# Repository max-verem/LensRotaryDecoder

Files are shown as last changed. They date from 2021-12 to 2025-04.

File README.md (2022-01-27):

# Lens Rotary Decoder

This project cover several cases on getting lens rotation info

## EZ-USB with Canon HJ14ex4.3B

This version cover getting virtual output of Canon HJ14ex4.3B lens output, please [follow](EZ-USB.md) detailed description

## MCU version

This version cover getting virtual output of Canon HJ14ex4.3B lens output and stanalone encoders, please [follow](MCU-NET.md) detailed description

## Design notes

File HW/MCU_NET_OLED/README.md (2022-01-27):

# MCU version of rotary decoder

This version cover both cases:
* Canon HJ14ex4.3B lens virtual output encoder
* Standalone rotary encoders

## Schematic
schematic

## PCB
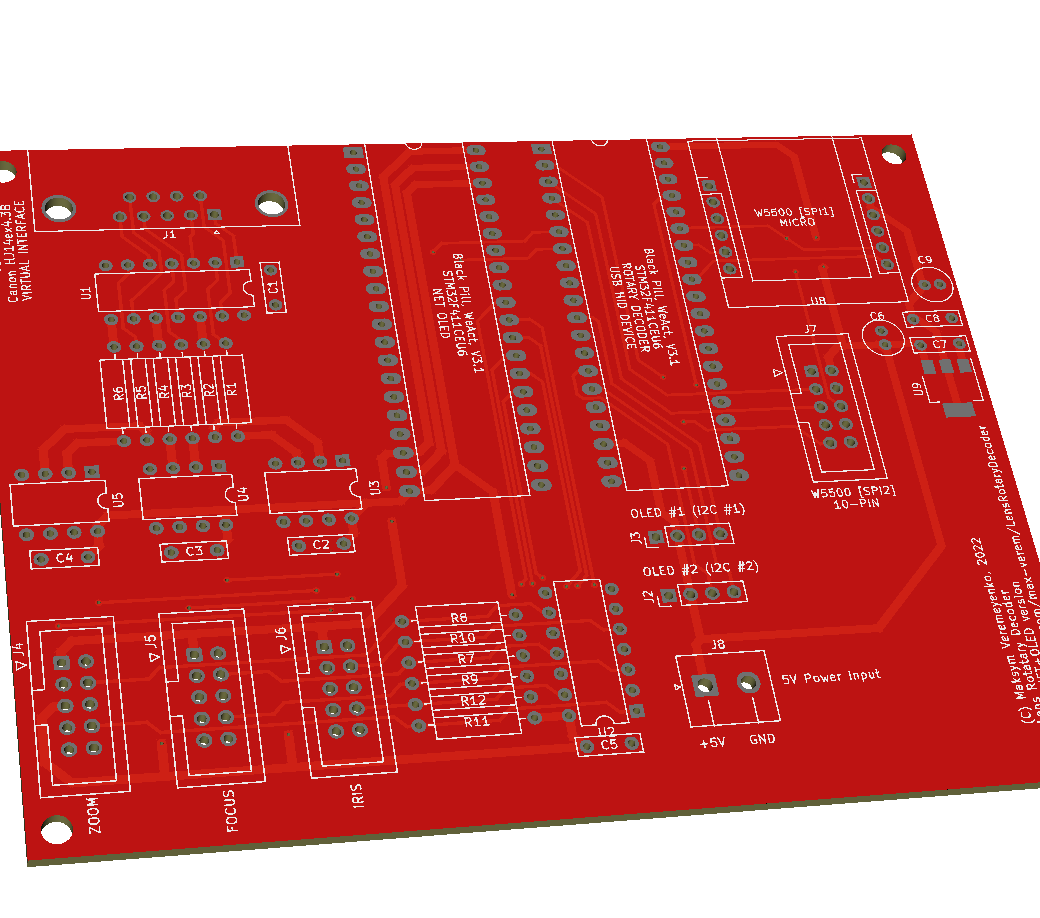
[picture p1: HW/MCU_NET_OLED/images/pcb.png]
pcb


[gerber file](gerber/)

## Firmware

* [rotary decoder firmware source](../../STM32/STM32F411CEU6_RotaryDecoder_3X)
* [NET OLED interface firmware source](../../STM32/STM32F411CEU6_FPGA_UART)

## Hardcoded things

* MAC address of this device is **BA:DE:C0:DE:XX:00** where **XX* is a *unique* hex value for that board
* IP address of FreeD receiver is broadcast (255.255.255.255), destination port is **60000** + **XX**

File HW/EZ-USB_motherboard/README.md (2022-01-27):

# EZ-USB (CY7C68013A EZ-USB FX2LP) based decoder board for Canon HJ14ex4.3B IRSE 

## Schematic
schematic

## PCB
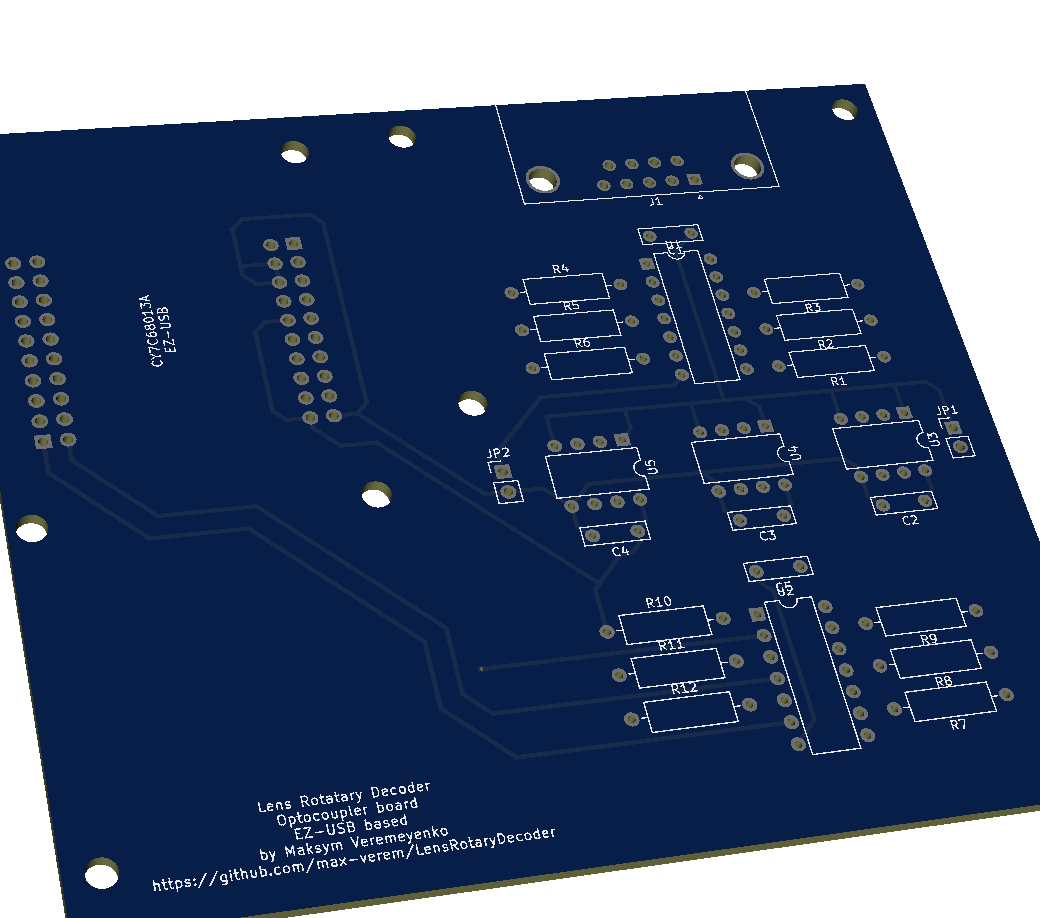
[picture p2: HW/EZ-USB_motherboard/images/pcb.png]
pcb


## GERBER
You can download [gerber archive here](gerber/)

## Final board
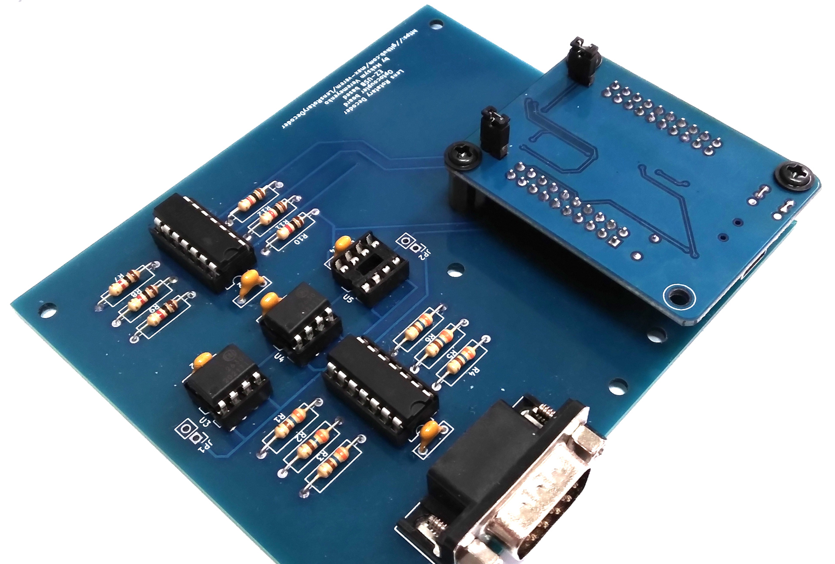
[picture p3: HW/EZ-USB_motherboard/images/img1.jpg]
view 1

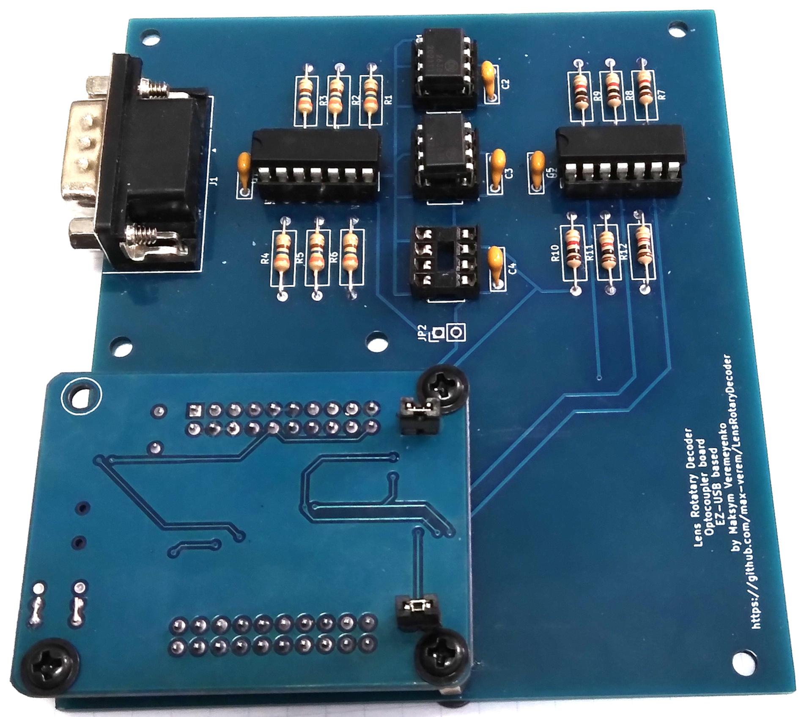
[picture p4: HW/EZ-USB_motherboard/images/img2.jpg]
view 2


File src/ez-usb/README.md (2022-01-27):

# EZ-USB (CY7C68013A EZ-USB FX2LP) based decoder software for Canon HJ14ex4.3B IRSE

## udev (autoloading firmware for EZ-USB)

**/etc/udev/rules.d/90-fx.rules**:
```
SUBSYSTEM=="usb", ACTION=="add", ATTR{idVendor}=="04b4", ATTR{idProduct}=="8613", SYMLINK+="fx2lp-devkit", RUN+="/usr/sbin/fxload -D $tempnode -t fx2lp -I /usr/share/sigrok-firmware/fx2lafw-sigrok-fx2-8ch.fw.hex"
```
make sure **fxload** and **sigrok** packages installed

## diagnostic

after connecting this board to usb port you should notice log messages:
```
[700467.647356] usb 1-1.2: new high-speed USB device number 53 using dwc_otg
[700467.747908] usb 1-1.2: New USB device found, idVendor=04b4, idProduct=8613, bcdDevice=a0.01
[700467.747927] usb 1-1.2: New USB device strings: Mfr=0, Product=0, SerialNumber=0
[700467.748835] usbtest 1-1.2:1.0: FX2 device
[700467.748853] usbtest 1-1.2:1.0: high-speed {control bulk-in bulk-out} tests (+alt)
[700467.845413] usb 1-1.2: USB disconnect, device number 53
[700469.351363] usb 1-1.2: new high-speed USB device number 54 using dwc_otg
[700469.452666] usb 1-1.2: New USB device found, idVendor=1d50, idProduct=608c, bcdDevice= 0.01
[700469.452690] usb 1-1.2: New USB device strings: Mfr=1, Product=2, SerialNumber=3
[700469.452705] usb 1-1.2: Product: fx2lafw
[700469.452720] usb 1-1.2: Manufacturer: sigrok
[700469.452735] usb 1-1.2: SerialNumber: sigrok FX2 8ch
```
and **lsusb** will show:
```
Bus 001 Device 054: ID 1d50:608c OpenMoko, Inc. Fx2lafw
```

## operating
binary start:
```
./ez_usb_rot_dec --freed-target=10.1.5.65:50050 --freed-div=150 --freed-id=8
```
where:
* *--freed-target=10.1.5.65:50050* is a target host:port where FreeD packet will be sent
* *--freed-id=8*  is a camera id in FreeD protocol
* *--freed-div=150* defines a rate for sending UDP packets to FreeD received, this value is a divider of USB transfers counter
* *--log-file-name=/tmp/log* where log will be save
* *--demonize* start in daemon mode

after startup in non-daemon mode it outputs logs and statistic:
```
  [2022-01-27 10:06:27.543] ez_usb_rot_dec-v1.0-86-gd7c67b8, Copyright by Maksym Veremeyenko (c) 2022
  [2022-01-27 10:06:27.544] ez_usb_reader_proc: Searching for 1D50:608C
  [2022-01-27 10:06:27.544] freed_sender_proc: Entering....
! [2022-01-27 10:06:27.548] freed_sender_proc: new target [10.1.5.65:50050]
! [2022-01-27 10:06:27.568] ez_usb_reader_proc: endpoint=130 (0x82)
! [2022-01-27 10:06:27.569] ez_usb_reader_proc: fw_version Major=01, Minor=04, revision 01
! [2022-01-27 10:06:27.586] command_start_acquisition: GPIF delay = 11, clocksource = 48MHz.
  [2022-01-27 10:06:27.586] counter_proc: Entering...
|          0 |          0 |          0| [       27078656  ]
```

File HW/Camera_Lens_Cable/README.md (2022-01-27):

# Hirose 20 Pin Male HR25-9P-20P for Canon HJ14ex4.3B IRSE

## Schematic

Cable

## Assembling

You can use separate connector **Hirose HR25A-9P-20P** connector:
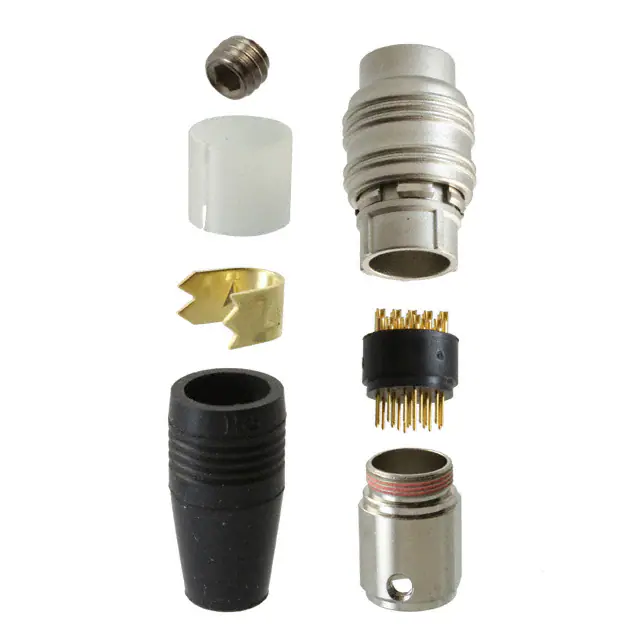
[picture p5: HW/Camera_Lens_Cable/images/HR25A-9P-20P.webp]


and assemble cable:
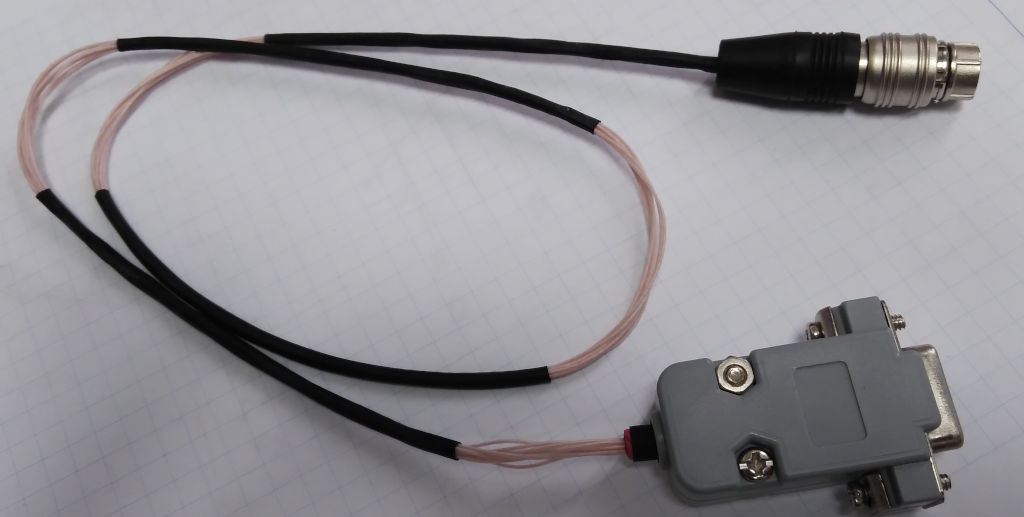
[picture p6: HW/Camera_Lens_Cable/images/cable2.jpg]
Cable


another way is to buy cable with soldered **Alvin’s Cables Hirose 20 Pin Male HR25-9P-20P to Open End Shield Cable for Canon Fujinon ENG Lens 1M** cable:
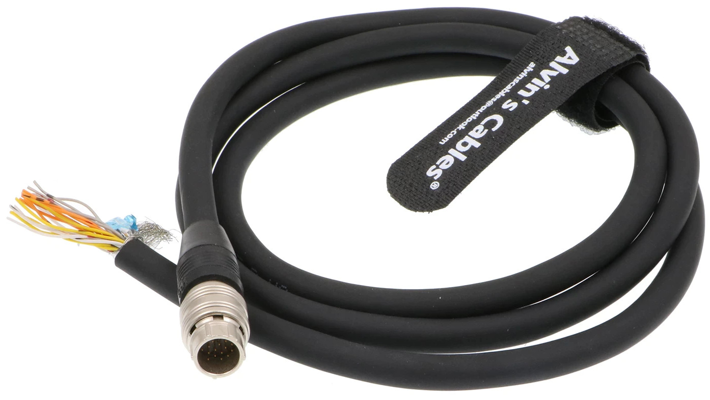
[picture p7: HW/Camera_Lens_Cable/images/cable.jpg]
Cable


that you can buy [here](https://www.aliexpress.com/item/1005001689120693.html) and [here](https://www.amazon.co.uk/Alvins-Cables-Hirose-HR25-9P-20P-Fujinon/dp/B08MC7KPMV)

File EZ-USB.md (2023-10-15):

# EZ-USB (CY7C68013A EZ-USB FX2LP) based decoder for Canon HJ14ex4.3B IRSE virtual output

Lens **Canon HJ14ex4.3B** has output that can provide information from internal rotary encoder.

# Functional schematic
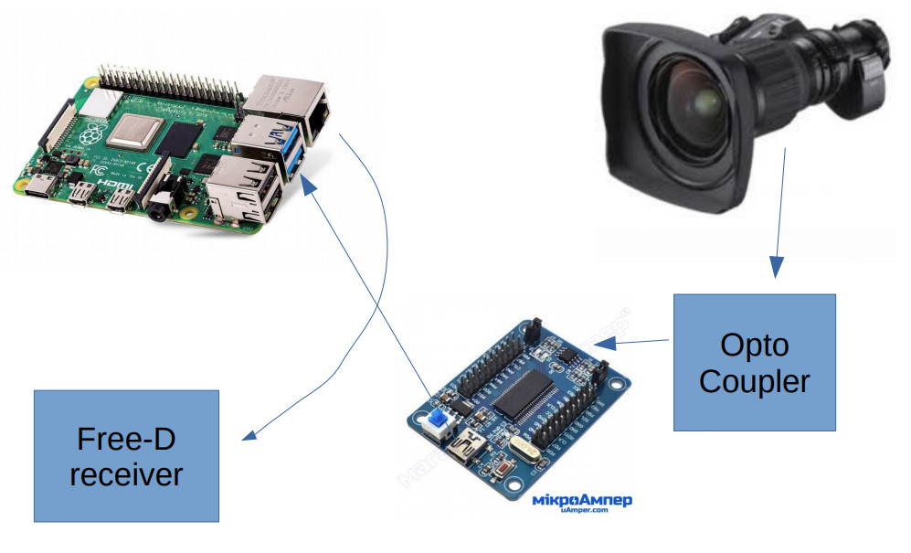
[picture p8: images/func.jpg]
func


# Signal direction
* [Cable](HW/Camera_Lens_Cable/) connected to first lens output provides rotary decoder info of Zoom/Focus/Iris
* This data sent to [opto-isolator board](HW/EZ-USB_motherboard/) that bridged with CY7C68013A based logic analizer board
* Logic analizer connected by USB cable mini-pc
* [Software](src/ez-usb/) that perform decoding of raw data received from lens installed on mini pc. After decoding, it compose Free-D packets sent to reciever (render station or [lens calibrarting server](https://github.com/max-verem/VRPN-LensCalibration))

# Final device
for final device standart case was used:

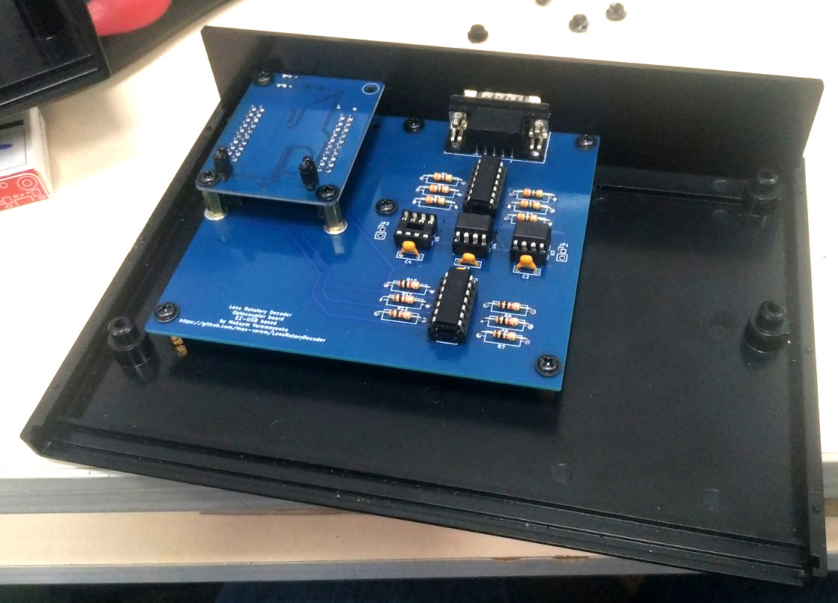
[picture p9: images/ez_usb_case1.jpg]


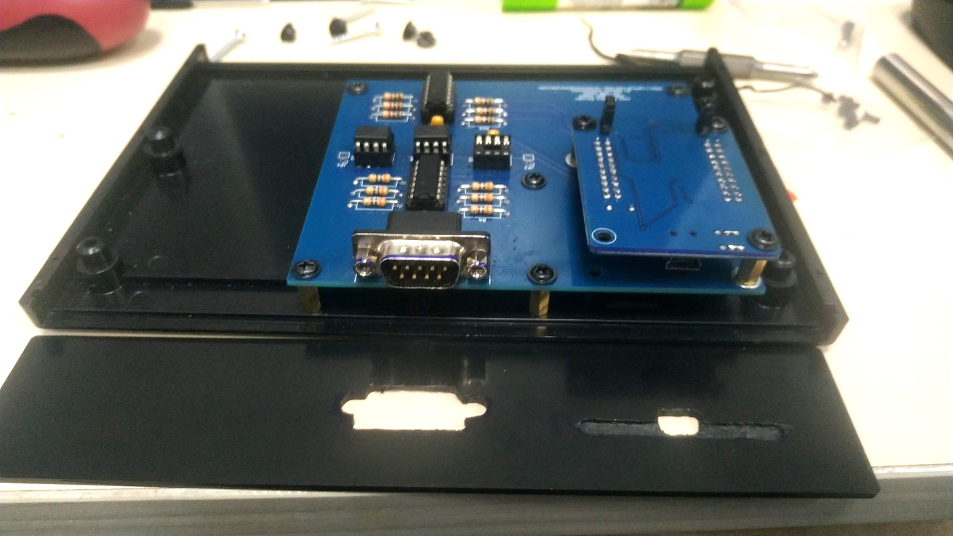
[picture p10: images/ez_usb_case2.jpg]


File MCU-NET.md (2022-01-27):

# MCU version of rotary decoder for Canon HJ14ex4.3B IRSE virtual output or standalone rotary encoders

[Previous](EZ-USB.md) version require a lot of CPU power to decode data, so we developing more simplified version that could also cover standalone encoders support

## Functional diagram
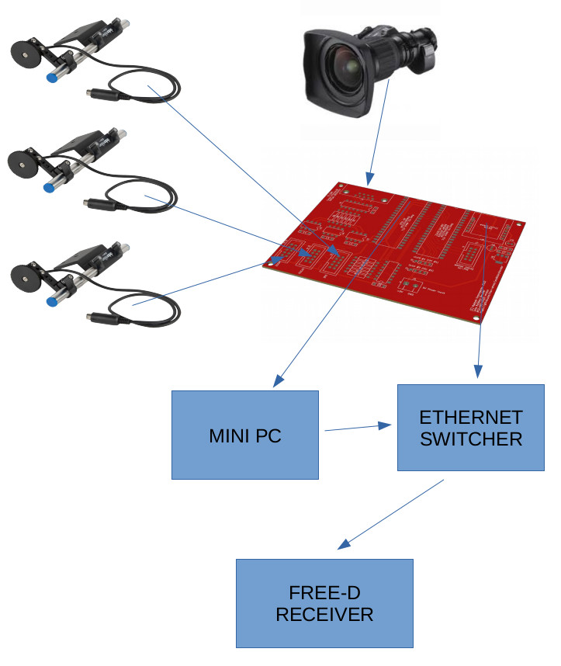
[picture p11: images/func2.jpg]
Functional diagram


## Implementation

[Core board](HW/MCU_NET_OLED/) perform all task for receiving/processing/sending data, it accept [Canon lens cable](HW/Camera_Lens_Cable/) for connecting lens directly.

Standalone encoders:

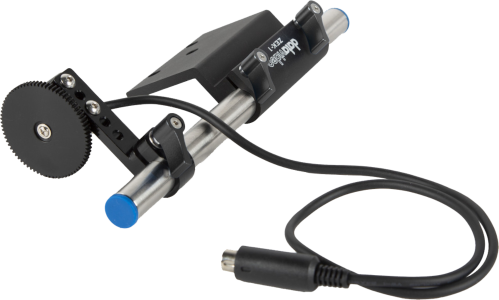
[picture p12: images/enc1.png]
example 1

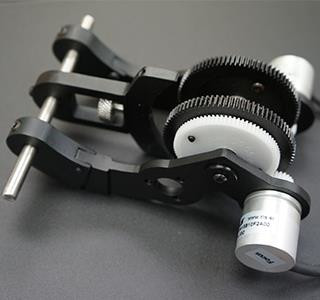
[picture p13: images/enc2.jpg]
example 2
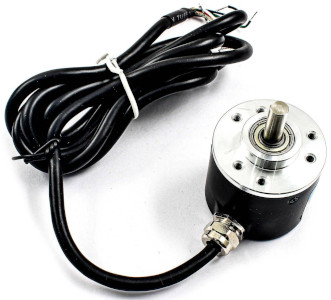
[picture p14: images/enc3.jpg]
example 3
 

could also be connection to that board (for Zoom/Focus/Iris)

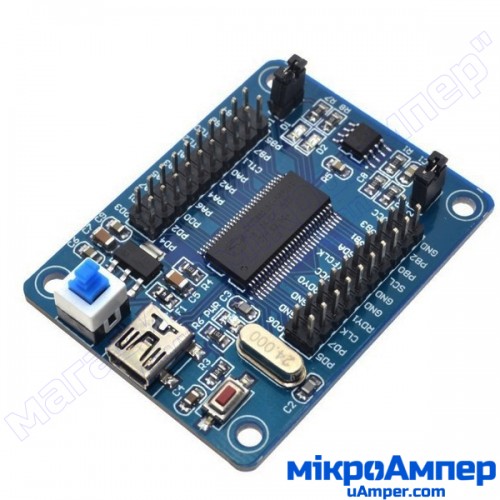
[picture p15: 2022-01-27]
images/ez-usb.jpg

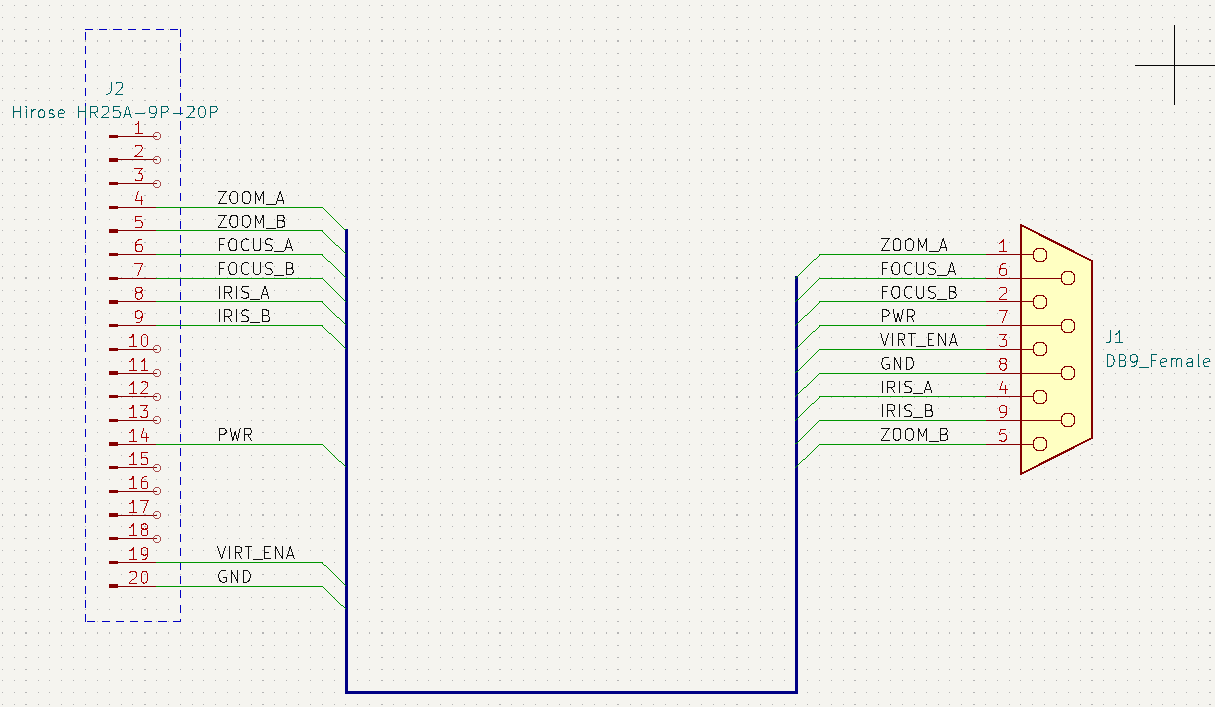
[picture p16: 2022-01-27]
HW/Camera_Lens_Cable/images/pic2.png

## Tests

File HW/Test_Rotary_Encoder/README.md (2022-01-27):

# Test Rotary Encoder

This is a EC11 rotary encoder with debouncing curcuit that is used in this project to debug and simulating purpose.

## Main module
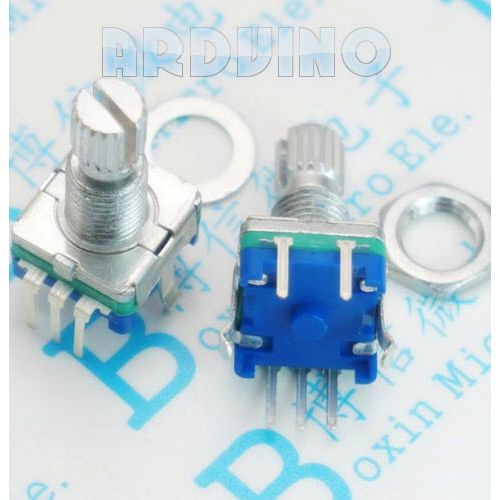
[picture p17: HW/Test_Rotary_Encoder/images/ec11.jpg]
EC11


## Schematic
Schematic

## PCB
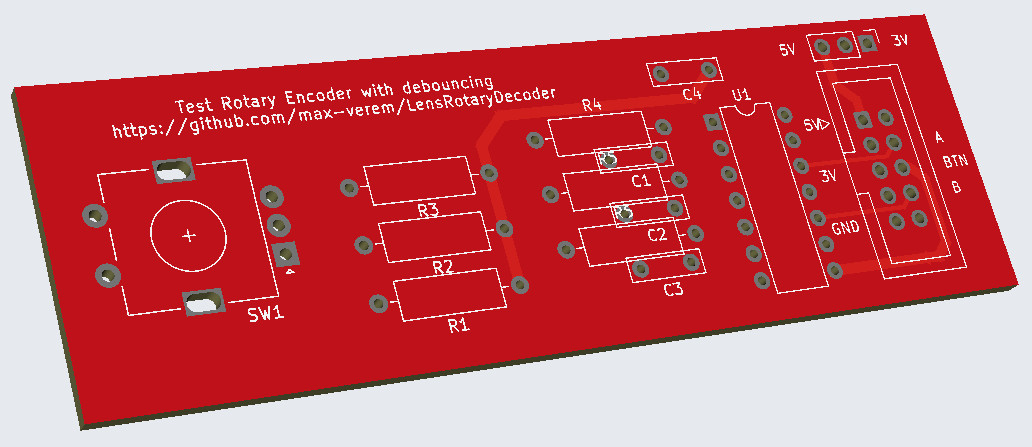
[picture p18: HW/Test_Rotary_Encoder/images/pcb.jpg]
PCB


gerber [file](gerber/)

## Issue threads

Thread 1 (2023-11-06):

encoder in Canon Lens

tappete, 2023-11-06:
Hi, I'm very interested of  this project and I would like to be able to send the encoder data to Arduino but I can't decode the output pulses from a Canon lens (I work in television and I have a lens like yours with Virtual Output).
I can read the data of the classic rotary encoders without any kind of problem but nothing to do for those integrated in the Canon lens, even after having created your circuit and taken the output pulses.
Are the Canon optics encoders different, what is the problem?

Many thanks and I hope you can help me!

Best regards,
Davide

max-verem, 2023-11-06:
I am not sure if Arduino has enough cpu power to decode sequence from lens. have a look on diagram:

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

A/B pulses distance is about 1us.

tappete, 2023-11-06:
ok, so the output is a quadrature but very fast...

Thank you

Closed 2023-11-06.

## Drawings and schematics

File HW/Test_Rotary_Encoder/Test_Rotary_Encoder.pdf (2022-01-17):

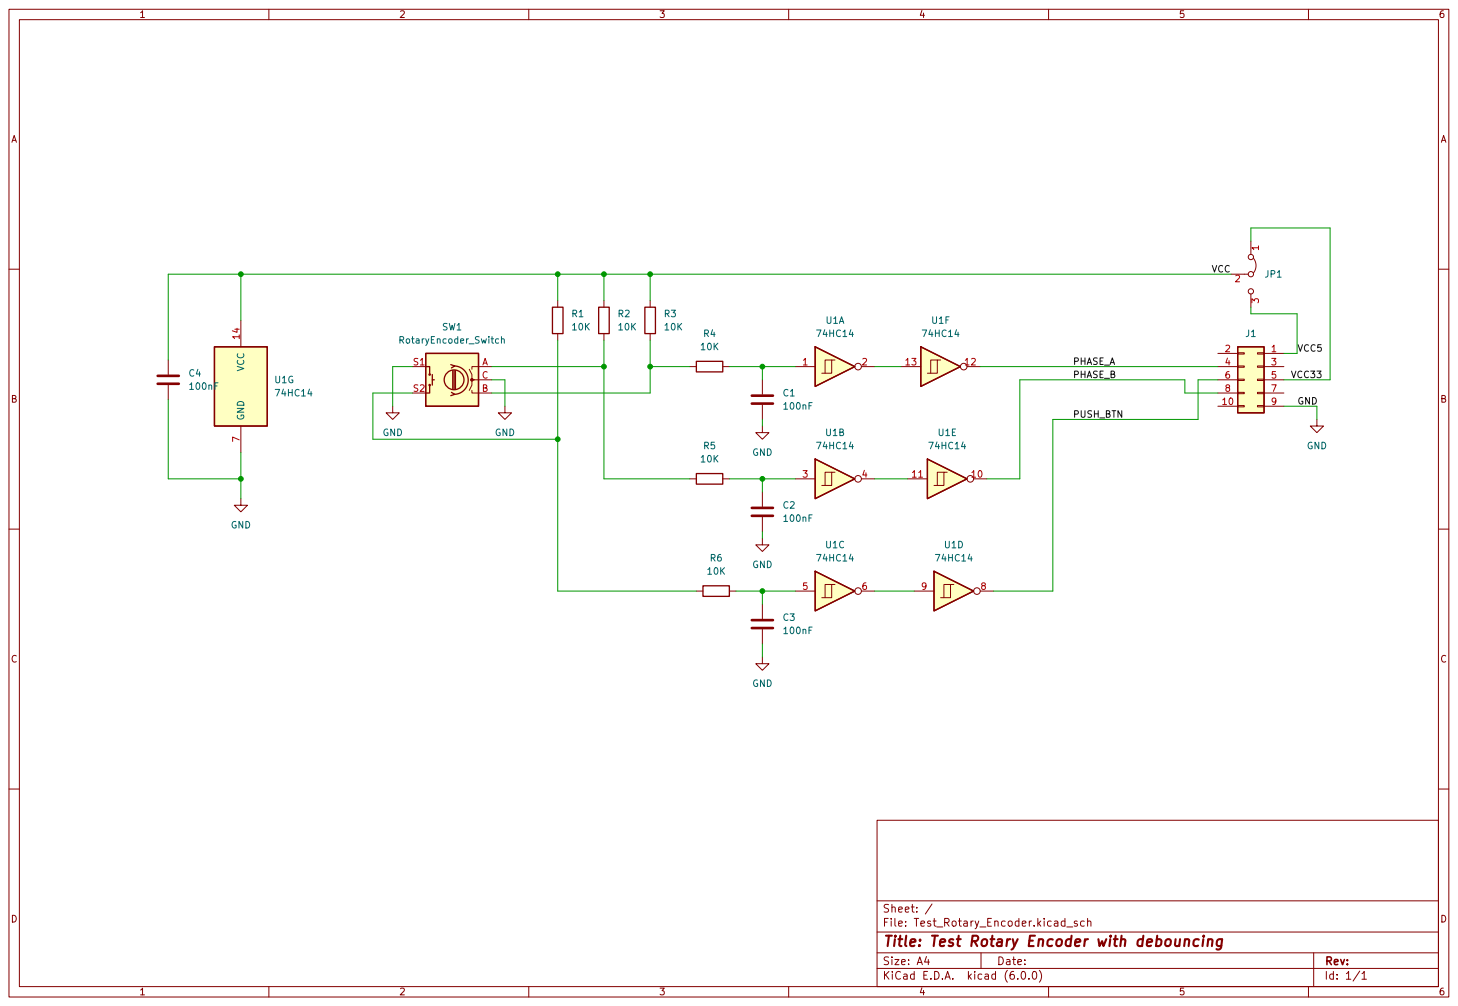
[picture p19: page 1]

File: Test_Rotary_Encoder.kicad_sch Sheet: / VCC 14 GND

Id: 1/1 Title: Test Rotary Encoder with debouncing

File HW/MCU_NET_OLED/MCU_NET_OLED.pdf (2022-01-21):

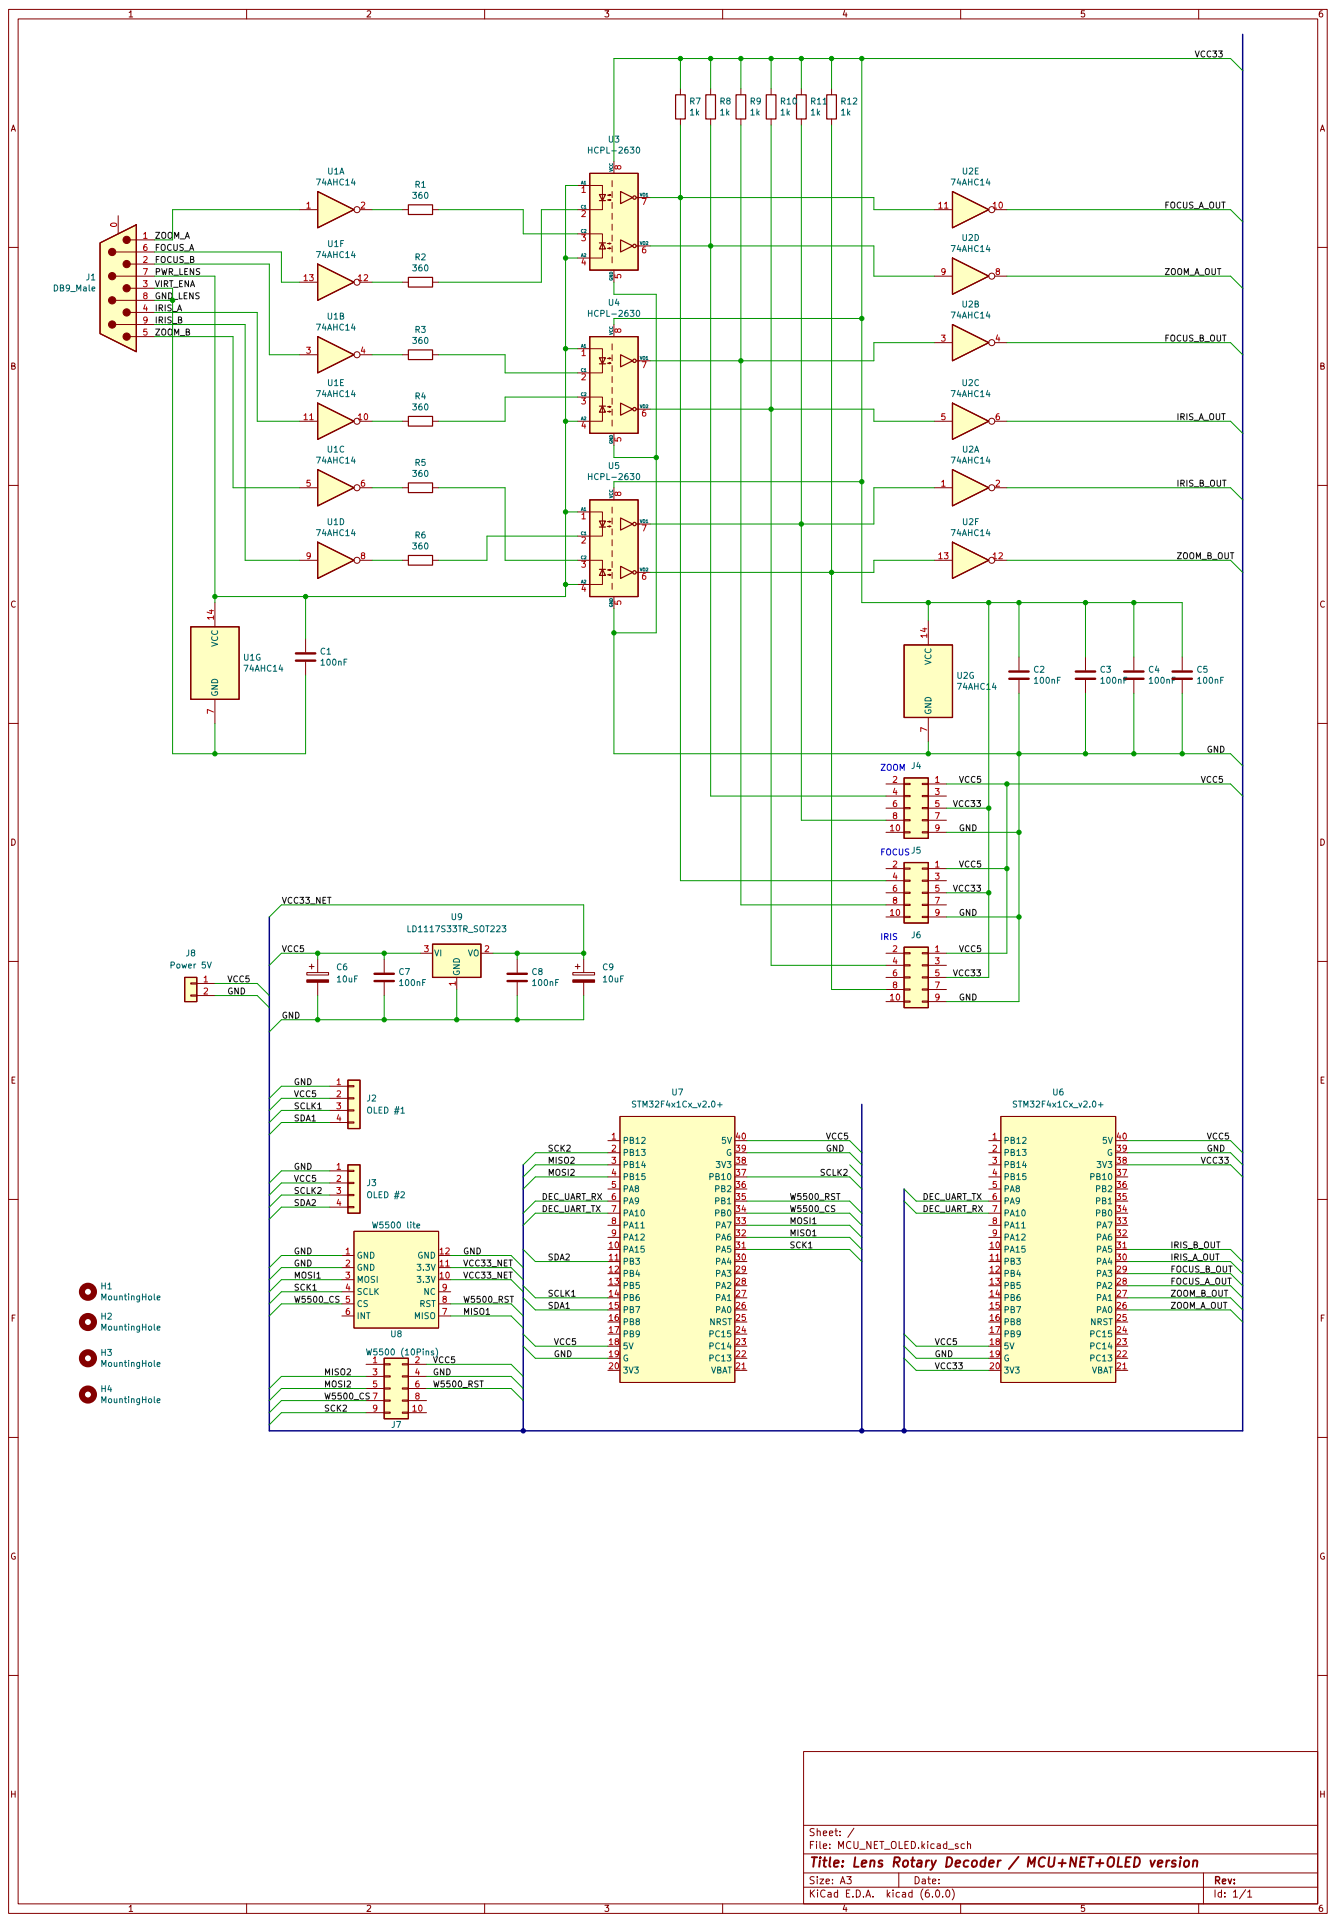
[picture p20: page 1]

File: MCU_NET_OLED.kicad_sch Sheet: /
Id: 1/1 Title: Lens Rotary Decoder / MCU+NET+OLED version

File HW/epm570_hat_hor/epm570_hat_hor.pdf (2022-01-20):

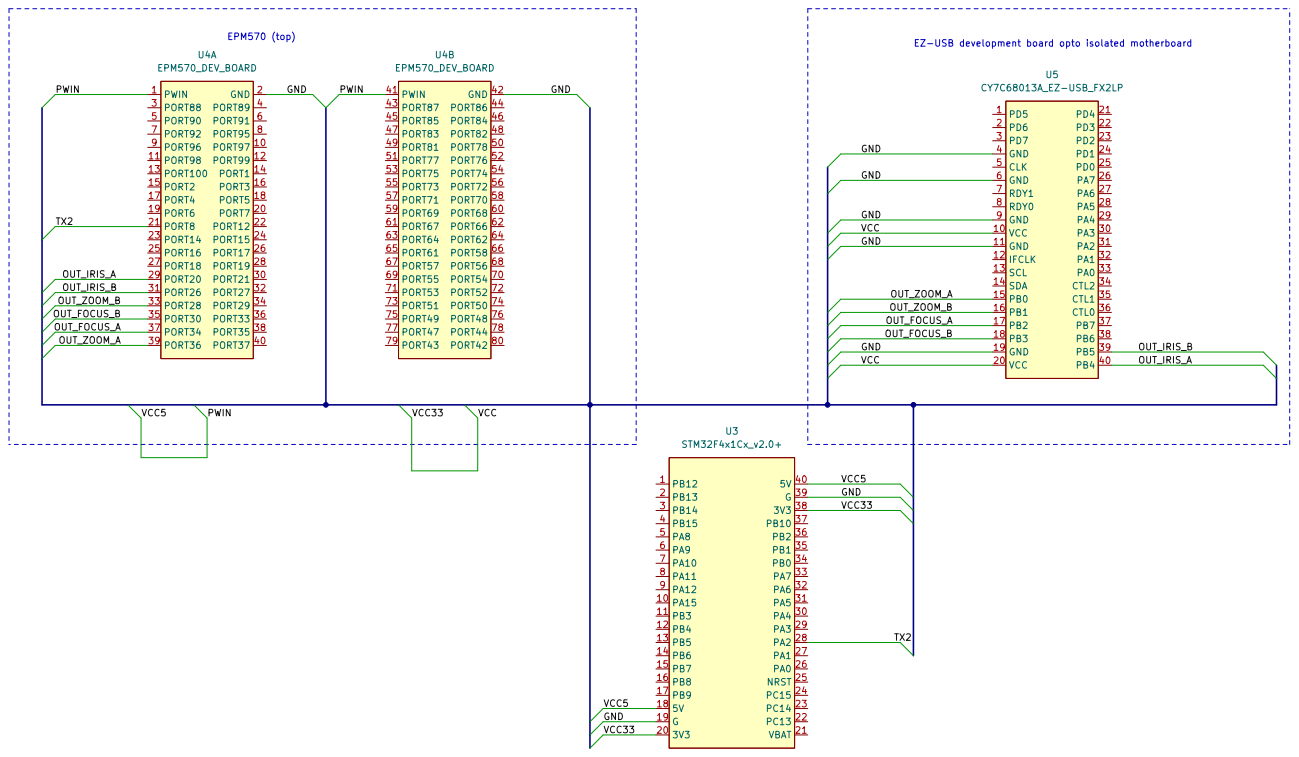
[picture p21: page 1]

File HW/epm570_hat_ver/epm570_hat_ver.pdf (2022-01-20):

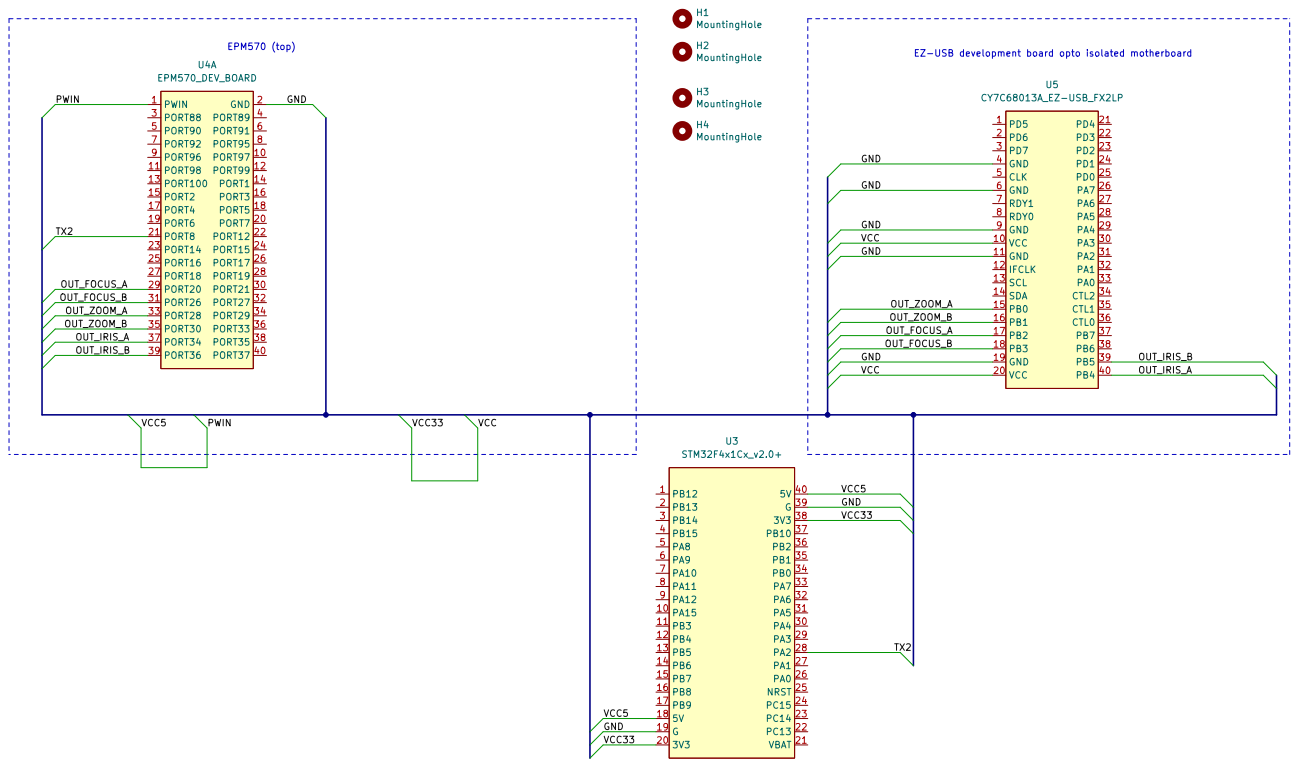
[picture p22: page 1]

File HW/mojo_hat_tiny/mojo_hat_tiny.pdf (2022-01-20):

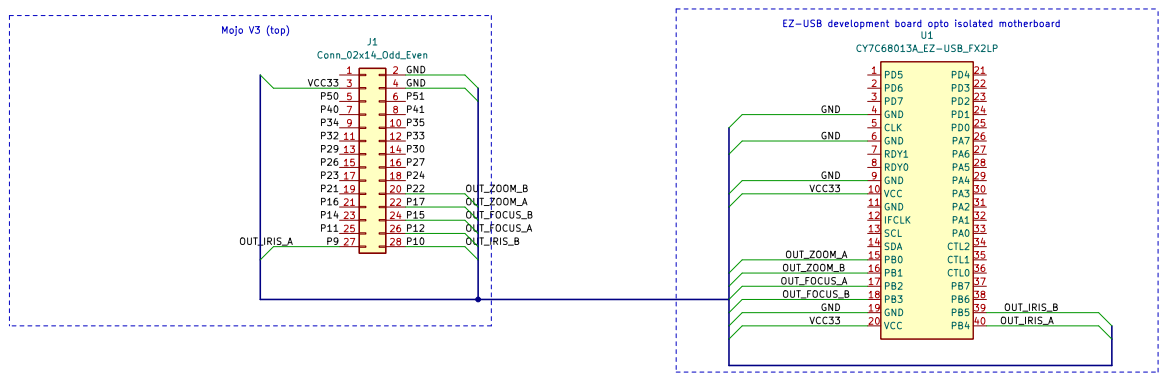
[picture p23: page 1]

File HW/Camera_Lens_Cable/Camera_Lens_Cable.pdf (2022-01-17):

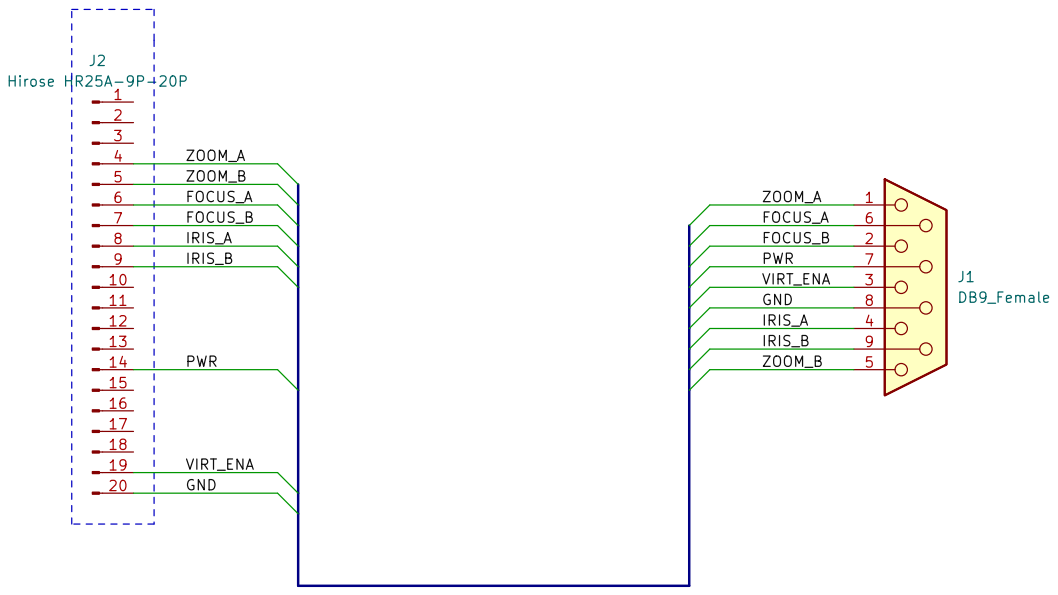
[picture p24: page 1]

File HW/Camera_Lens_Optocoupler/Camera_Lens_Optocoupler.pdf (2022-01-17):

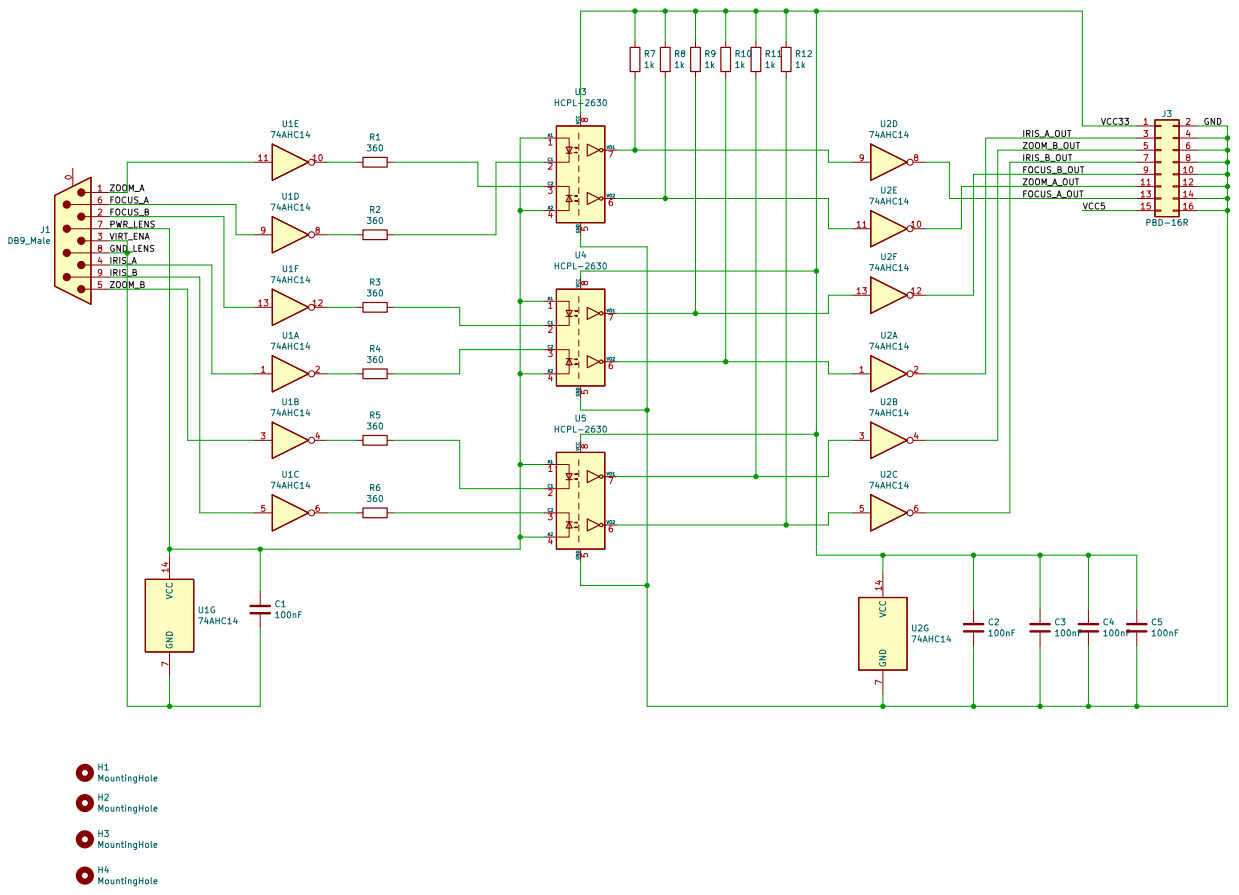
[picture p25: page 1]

11 | | 12
13 | | 14

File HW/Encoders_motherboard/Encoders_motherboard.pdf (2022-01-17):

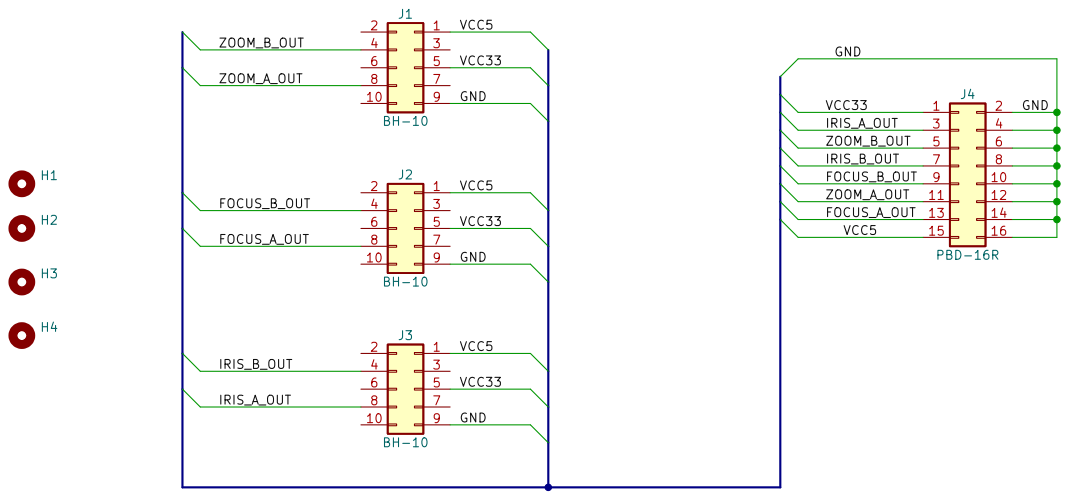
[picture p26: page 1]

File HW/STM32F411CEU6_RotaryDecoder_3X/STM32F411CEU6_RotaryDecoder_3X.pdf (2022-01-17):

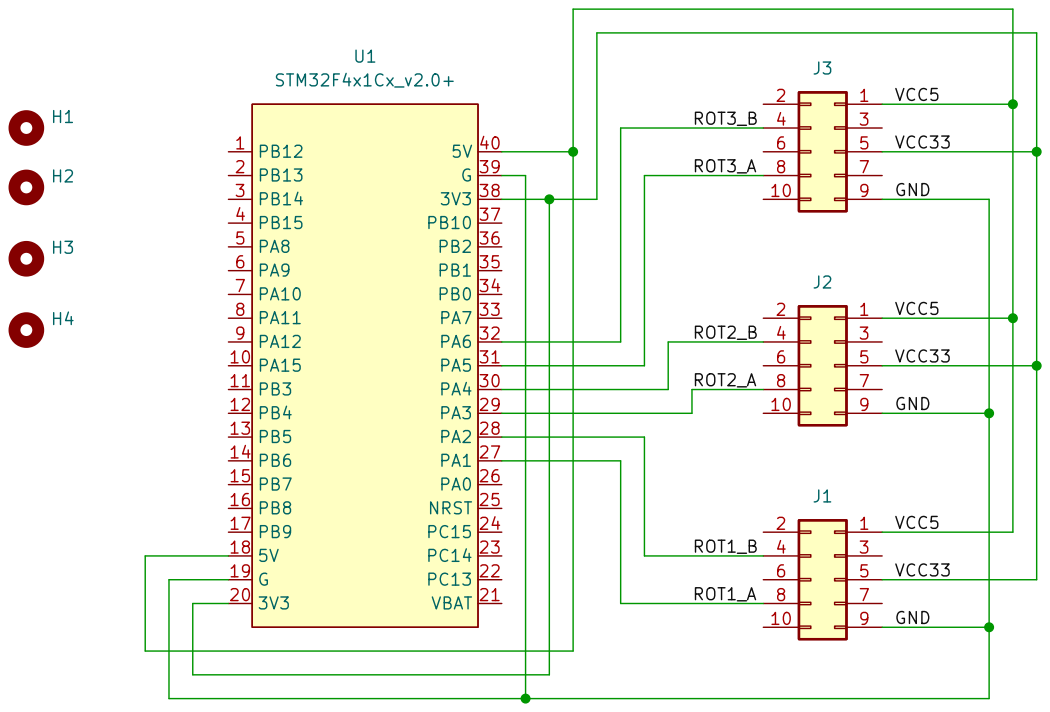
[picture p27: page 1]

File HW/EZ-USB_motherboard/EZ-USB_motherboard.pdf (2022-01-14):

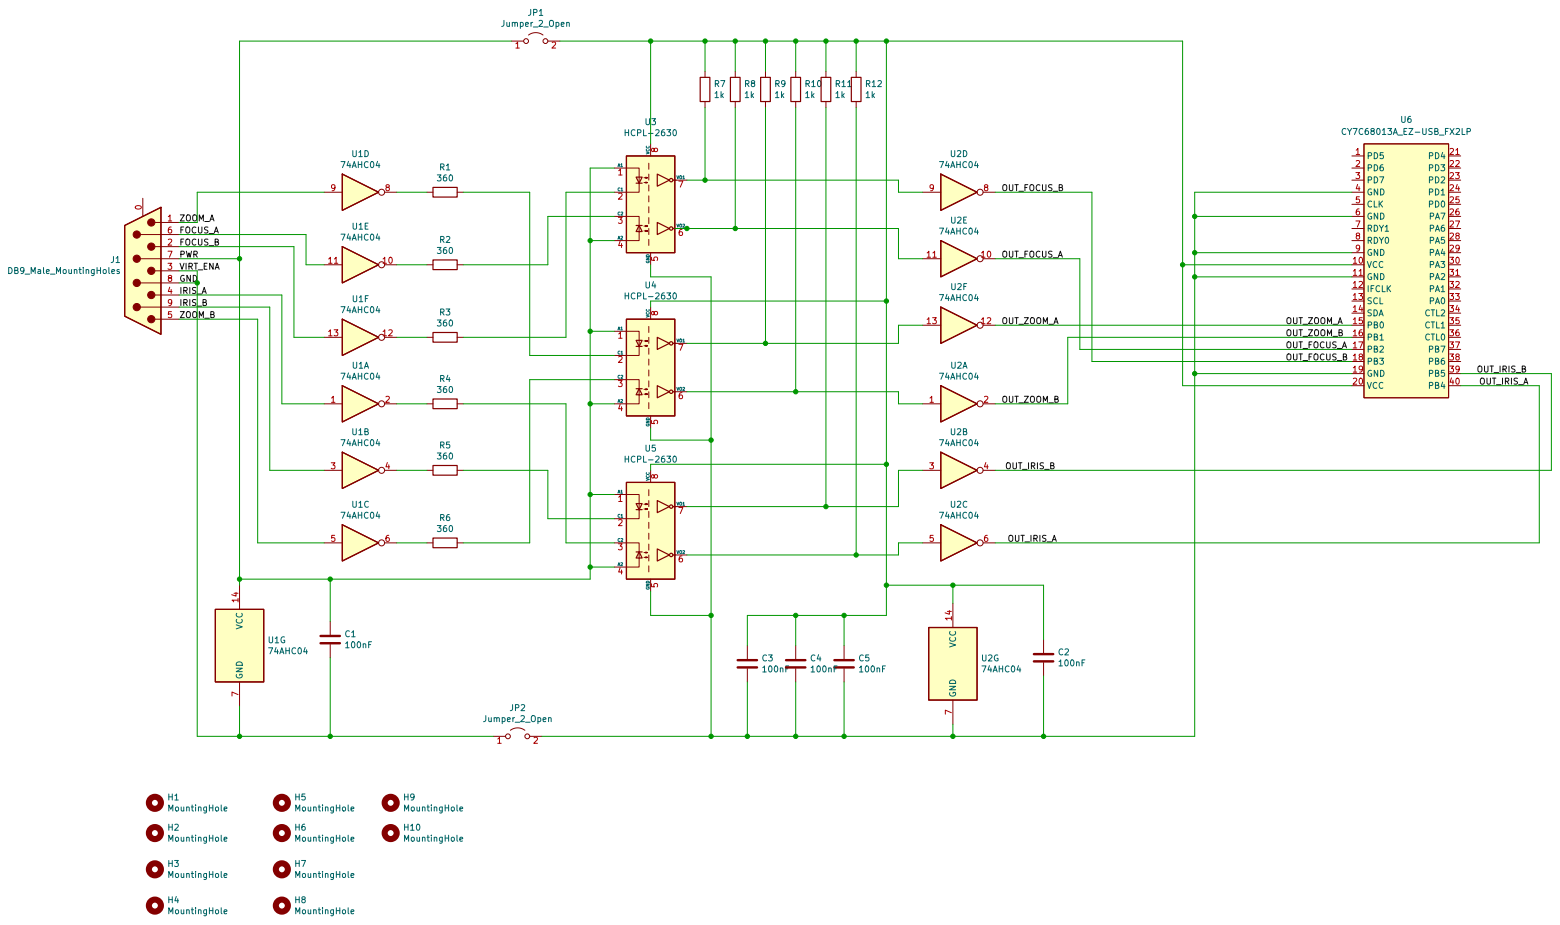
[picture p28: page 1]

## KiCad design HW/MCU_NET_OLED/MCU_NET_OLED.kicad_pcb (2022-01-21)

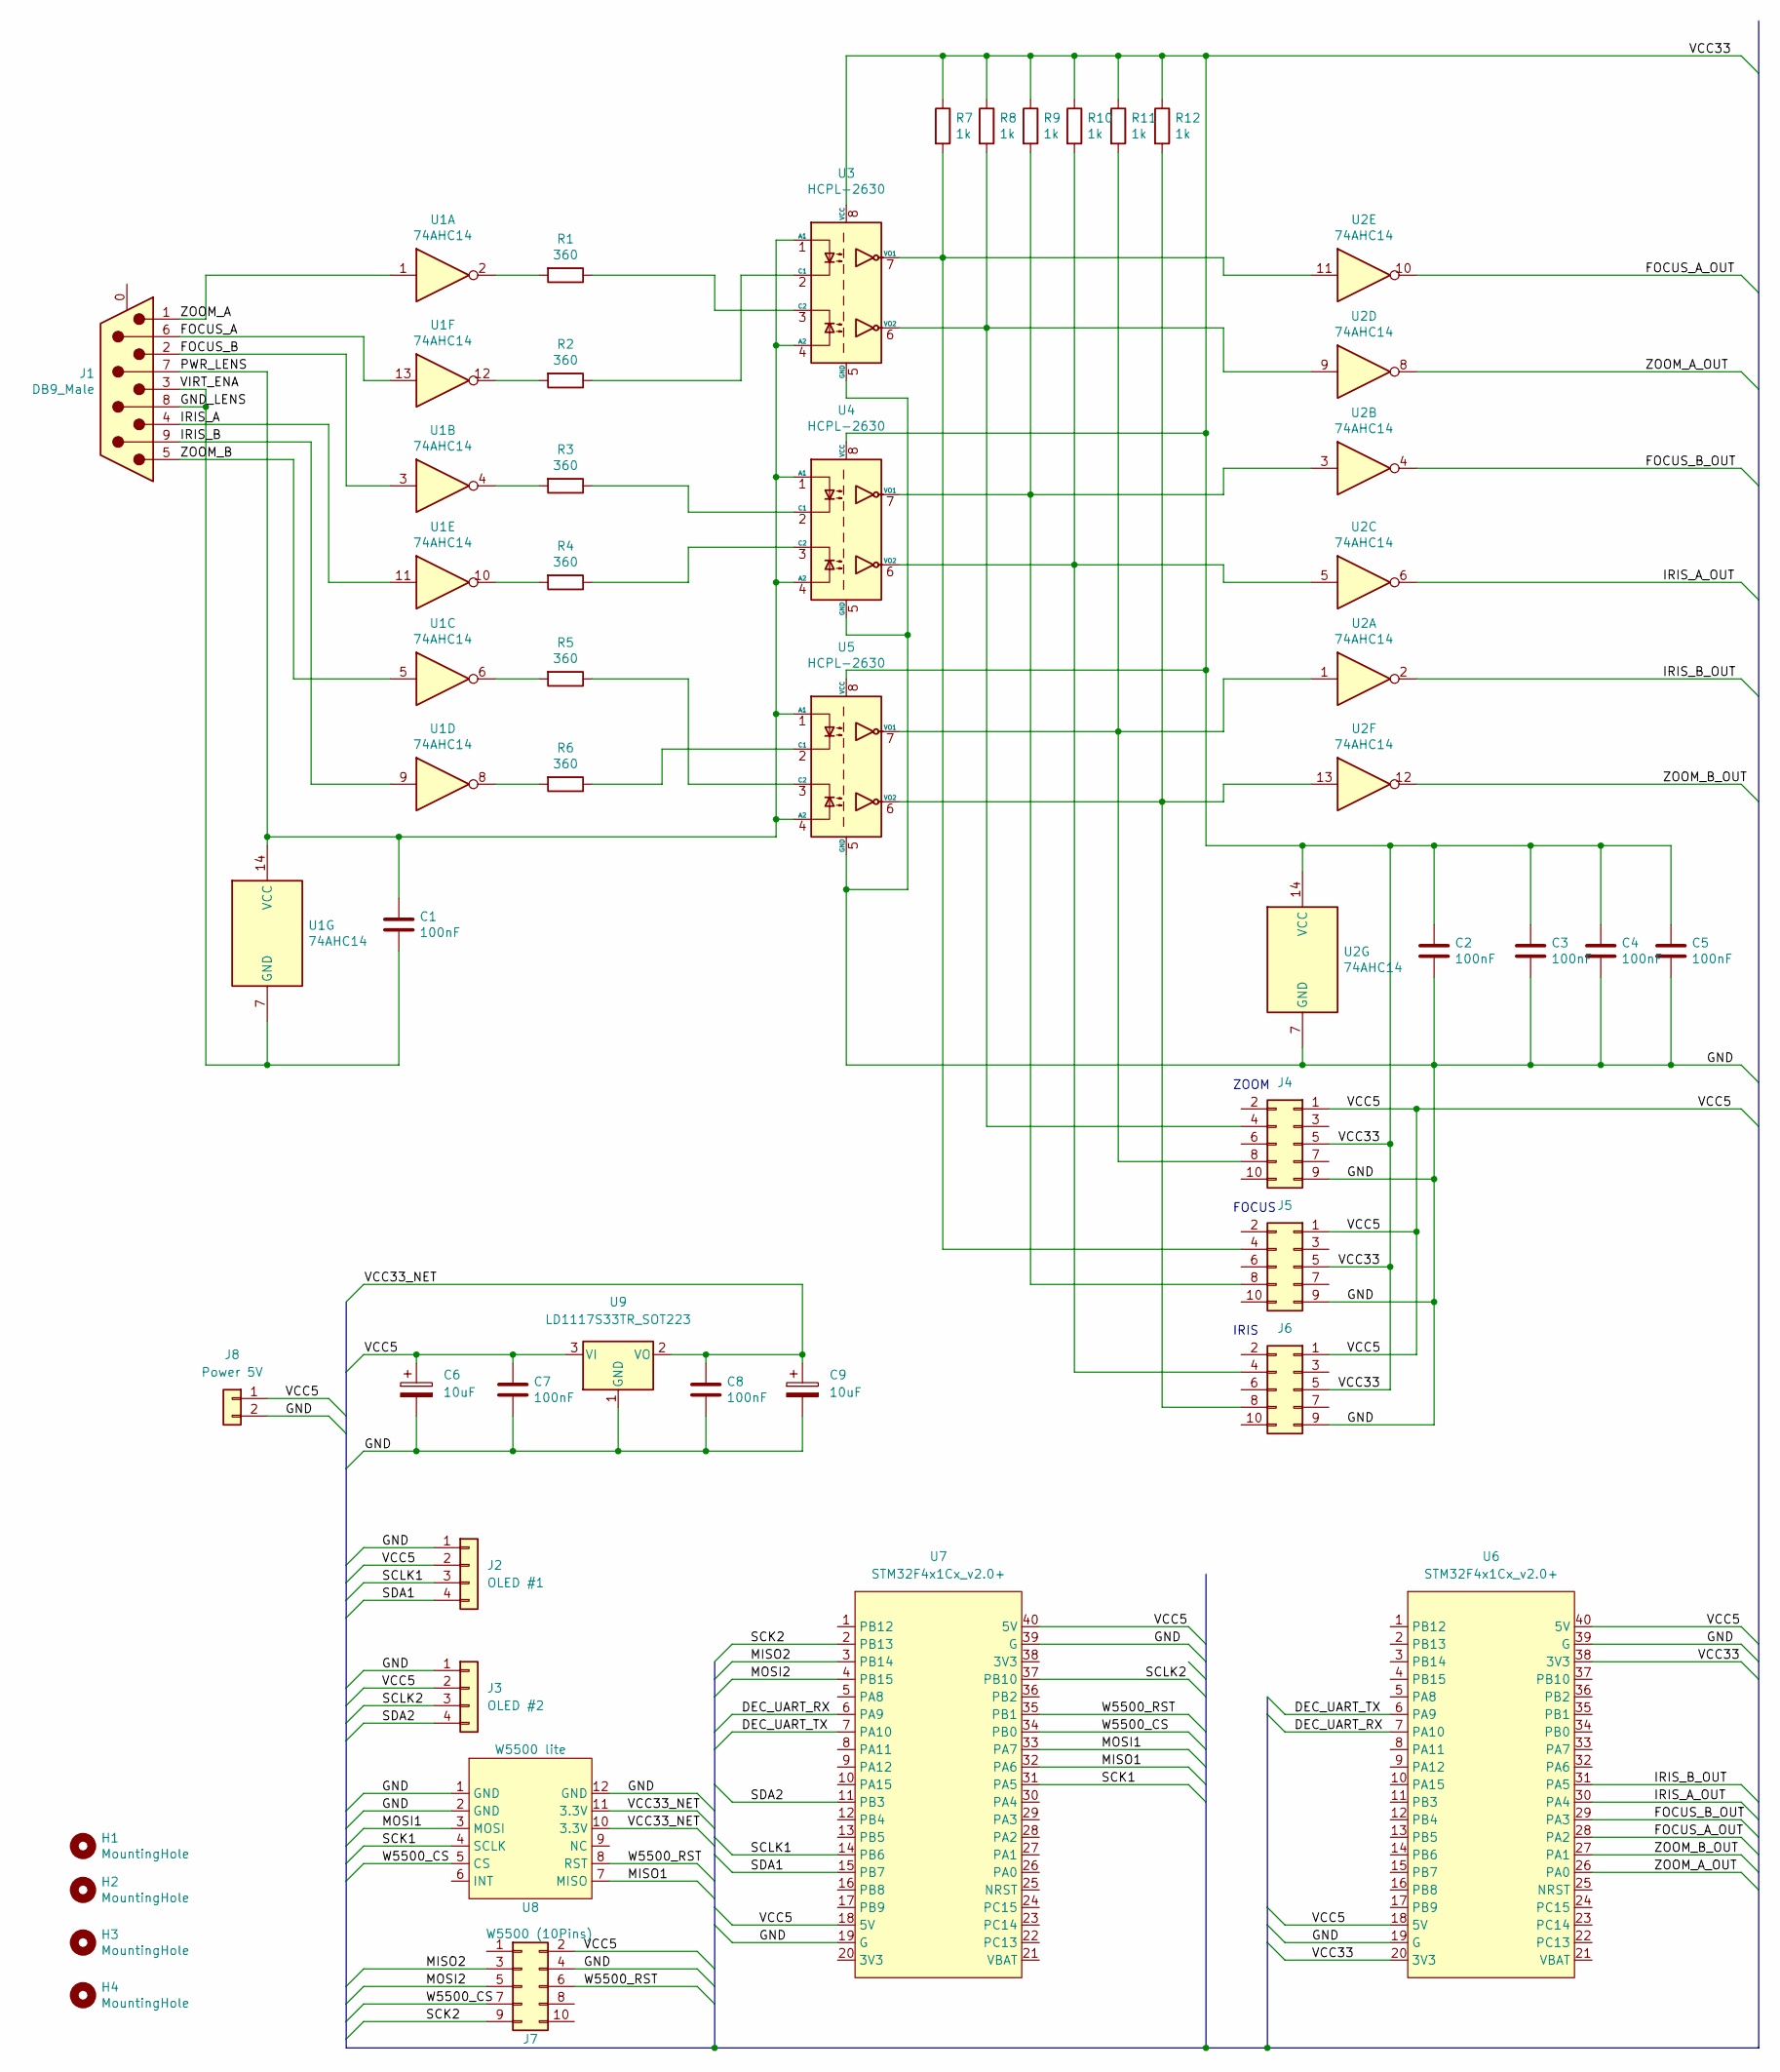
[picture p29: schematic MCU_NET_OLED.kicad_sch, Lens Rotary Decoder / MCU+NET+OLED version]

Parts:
C1, C2, C3, C4, C5, C7, C8: 100nF; C_Rect_L7.0mm_W2.0mm_P5.00mm
C6, C9: 10uF; C_Radial_D5.0mm_H11.0mm_P2.00mm
H1, H2, H3, H4: MountingHole; MountingHole_3.2mm_M3
J1: DB9_Male; DSUB-9_Male_Horizontal_P2.77x2.84mm_EdgePinOffset7.70mm_Hou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
J2: OLED #1; PinHeader_1x04_P2.54mm_Vertical
J3: OLED #2; PinHeader_1x04_P2.54mm_Vertical
J4, J5, J6: Conn_02x05_Odd_Even; IDC-Header_2x05_P2.54mm_Vertical
J7: W5500 (10Pins); IDC-Header_2x05_P2.54mm_Vertical
J8: Power 5V; JST_NV_B02P-NV_1x02_P5.00mm_Vertical
R1, R2, R3, R4, R5, R6: 360; R_Axial_DIN0309_L9.0mm_D3.2mm_P12.70mm_Horizontal
R7, R8, R9, R10, R11, R12: 1k; R_Axial_DIN0309_L9.0mm_D3.2mm_P12.70mm_Horizontal
U1, U2: 74AHC14; DIP-14_W7.62mm
U3, U4, U5: HCPL-2630; DIP-8_W7.62mm
U6, U7: STM32F4x1Cx_v2.0+; DIP-40_W15.24mm_LongPads
U8: W5500 lite; W5500
U9: LD1117S33TR_SOT223; SOT-223-3_TabPin2

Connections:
/DEC_UART_RX: U6.7 (PA10), U7.6 (PA9)
/DEC_UART_TX: U6.6 (PA9), U7.7 (PA10)
/FOCUS_A: J1.6, U1.13
/FOCUS_A_OUT: U2.10, U6.28 (PA2)
/FOCUS_B: J1.2, U1.3
/FOCUS_B_OUT: U2.4, U6.29 (PA3)
/GND: C2.2, C3.2, C4.2, C5.2, C6.2, C7.2, C8.2, C9.2, J2.1, J3.1, J4.9, J5.9, J6.9, J7.4, J8.2, U2.7 (GND), U3.5 (GND), U4.5 (GND), U5.5 (GND), U6.19 (G), U6.39 (G), U7.19 (G), U7.39 (G), U8.1 (GND), U8.2 (GND), U8.12 (GND), U9.1 (GND)
/GND_LENS: C1.2, J1.3, J1.8, U1.7 (GND)
/IRIS_A: J1.4, U1.11
/IRIS_A_OUT: U2.6, U6.30 (PA4)
/IRIS_B: J1.9, U1.9
/IRIS_B_OUT: U2.2, U6.31 (PA5)
/MISO1: U7.32 (PA6), U8.7 (MISO)
/MISO2: J7.3, U7.3 (PB14)
/MOSI1: U7.33 (PA7), U8.3 (MOSI)
/MOSI2: J7.5, U7.4 (PB15)
/PWR_LENS: C1.1, J1.7, U1.14 (VCC), U3.1 (A1), U3.4 (A2), U4.1 (A1), U4.4 (A2), U5.1 (A1), U5.4 (A2)
/SCK1: U7.31 (PA5), U8.4 (SCLK)
/SCK2: J7.9, U7.2 (PB13)
/SCLK1: J2.3, U7.14 (PB6)
/SCLK2: J3.3, U7.37 (PB10)
/SDA1: J2.4, U7.15 (PB7)
/SDA2: J3.4, U7.11 (PB3)
/VCC5: C6.1, C7.1, J2.2, J3.2, J4.1, J5.1, J6.1, J7.2, J8.1, U6.18 (5V), U6.40 (5V), U7.18 (5V), U7.40 (5V), U9.3 (VI)
/VCC33: C2.1, C3.1, C4.1, C5.1, J4.5, J5.5, J6.5, R7.1, R8.1, R9.1, R10.1, R11.1, R12.1, U2.14 (VCC), U3.8 (VCC), U4.8 (VCC), U5.8 (VCC), U6.20 (3V3), U6.38 (3V3)
/VCC33_NET: C8.1, C9.1, U8.10 (3.3V), U8.11 (3.3V), U9.2 (VO)
/W5500_CS: J7.7, U7.34 (PB0), U8.5 (CS)
/W5500_RST: J7.6, U7.35 (PB1), U8.8 (RST)
/ZOOM_A: J1.1, U1.1
/ZOOM_A_OUT: U2.8, U6.26 (PA0)
/ZOOM_B: J1.5, U1.5
/ZOOM_B_OUT: U2.12, U6.27 (PA1)
unnamed: R1.1, U3.3 (C2)
unnamed: R1.2, U1.2
unnamed: R2.1, U3.2 (C1)
unnamed: R2.2, U1.12
unnamed: R3.1, U4.2 (C1)
unnamed: R3.2, U1.4
unnamed: R4.1, U4.3 (C2)
unnamed: R4.2, U1.10
unnamed: R5.1, U5.3 (C2)
unnamed: R5.2, U1.6
unnamed: R6.2, U1.8
unnamed: J5.4, R7.2, U2.11, U3.7 (VO1)
unnamed: J4.4, R8.2, U2.9, U3.6 (VO2)
unnamed: J5.8, R9.2, U2.3, U4.7 (VO1)
unnamed: J6.4, R10.2, U2.5, U4.6 (VO2)
unnamed: J4.8, R11.2, U2.1, U5.7 (VO1)
unnamed: J6.8, R12.2, U2.13, U5.6 (VO2)
unnamed: R6.1, U5.2 (C1)

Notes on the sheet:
IRIS
FOCUS
ZOOM

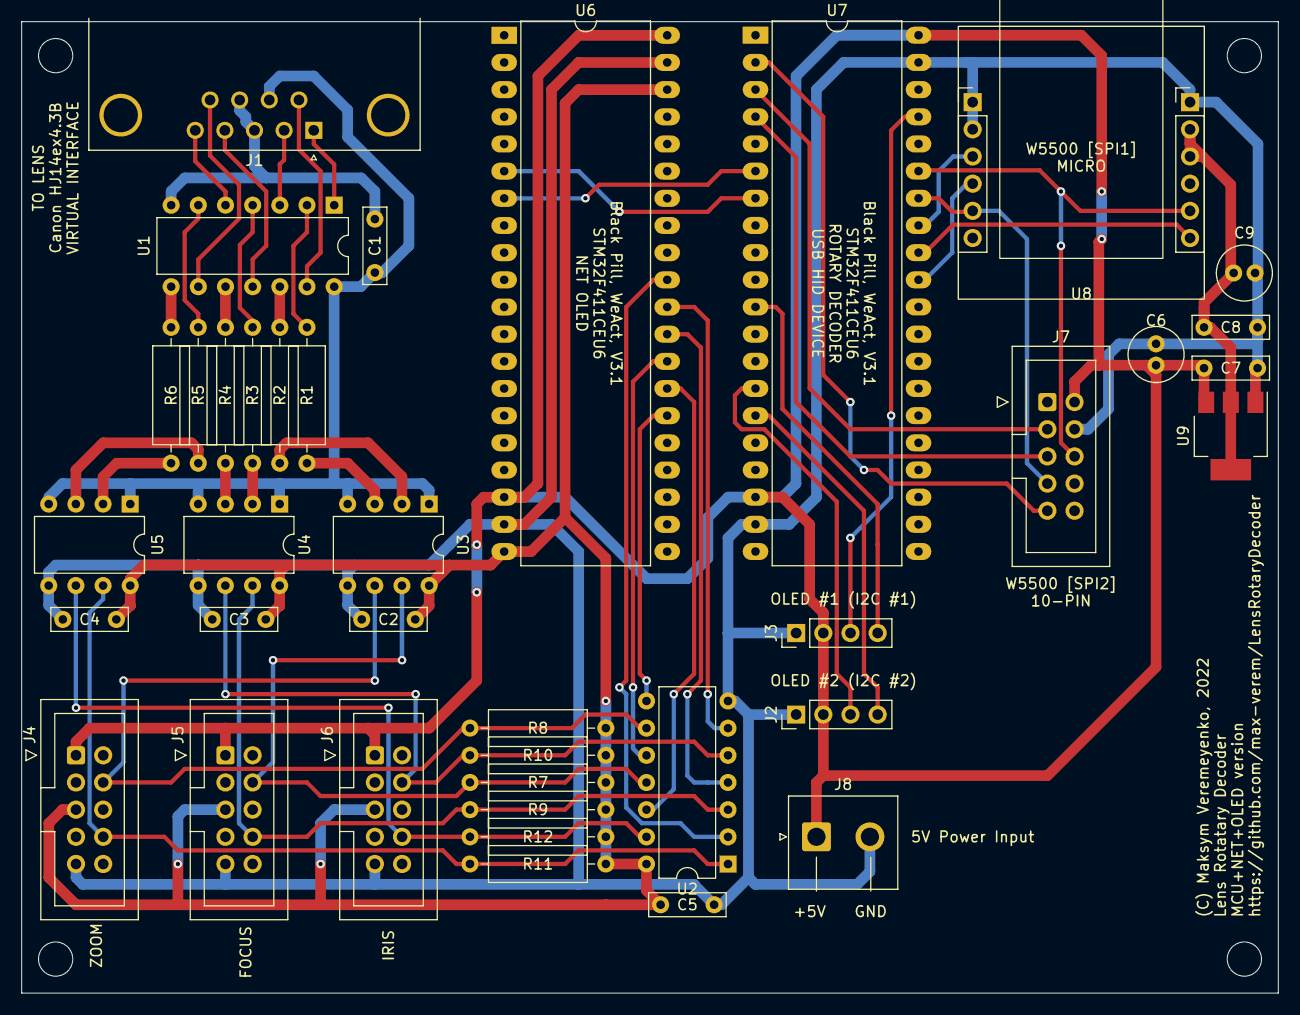
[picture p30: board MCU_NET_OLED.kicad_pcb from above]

Board: 2 copper layers, 117.5 x 90.8 mm, 42 parts (0 on the bottom side), 50 nets.

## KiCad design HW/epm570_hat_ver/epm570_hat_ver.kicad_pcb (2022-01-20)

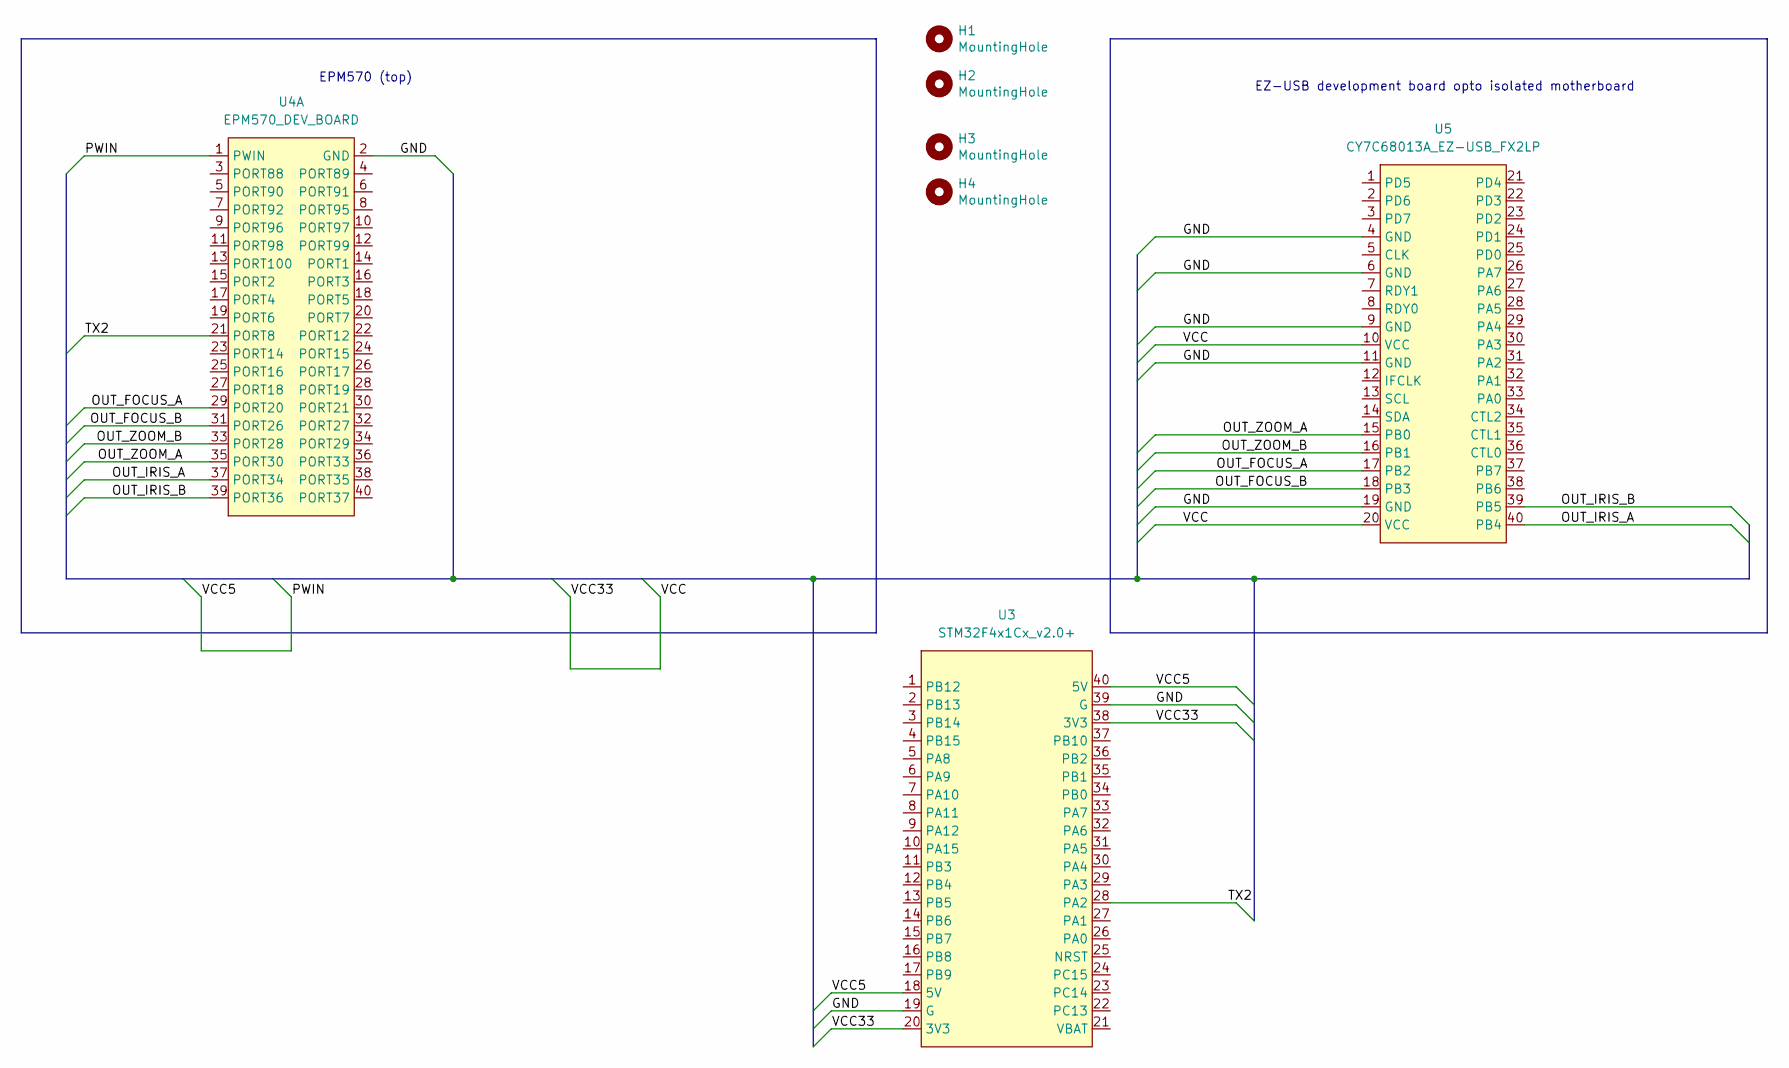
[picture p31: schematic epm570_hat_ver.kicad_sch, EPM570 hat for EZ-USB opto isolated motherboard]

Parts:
H1, H2, H3, H4: MountingHole; MountingHole_3.2mm_M3
U3: STM32F4x1Cx_v2.0+; DIP-40_W15.24mm_LongPads
U4: EPM570_DEV_BOARD; EPM570_DEV_BOARD_WEAK
U5: CY7C68013A_EZ-USB_FX2LP; CY7C68013A_EZ-USB_FX2LP_WEAK

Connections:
/GND: U3.19 (G), U3.39 (G), U4.2 (GND), U5.4 (GND), U5.6 (GND), U5.9 (GND), U5.11 (GND), U5.19 (GND)
/OUT_FOCUS_A: U4.29 (PORT20), U5.17 (PB2)
/OUT_FOCUS_B: U4.31 (PORT26), U5.18 (PB3)
/OUT_IRIS_A: U4.37 (PORT34), U5.40 (PB4)
/OUT_IRIS_B: U4.39 (PORT36), U5.39 (PB5)
/OUT_ZOOM_A: U4.35 (PORT30), U5.15 (PB0)
/OUT_ZOOM_B: U4.33 (PORT28), U5.16 (PB1)
/PWIN: U3.18 (5V), U3.40 (5V), U4.1 (PWIN)
/TX2: U3.28 (PA2), U4.21 (PORT8)
/VCC: U3.20 (3V3), U3.38 (3V3), U5.10 (VCC), U5.20 (VCC)

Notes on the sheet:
EZ-USB development board opto isolated motherboard
EPM570 (top)

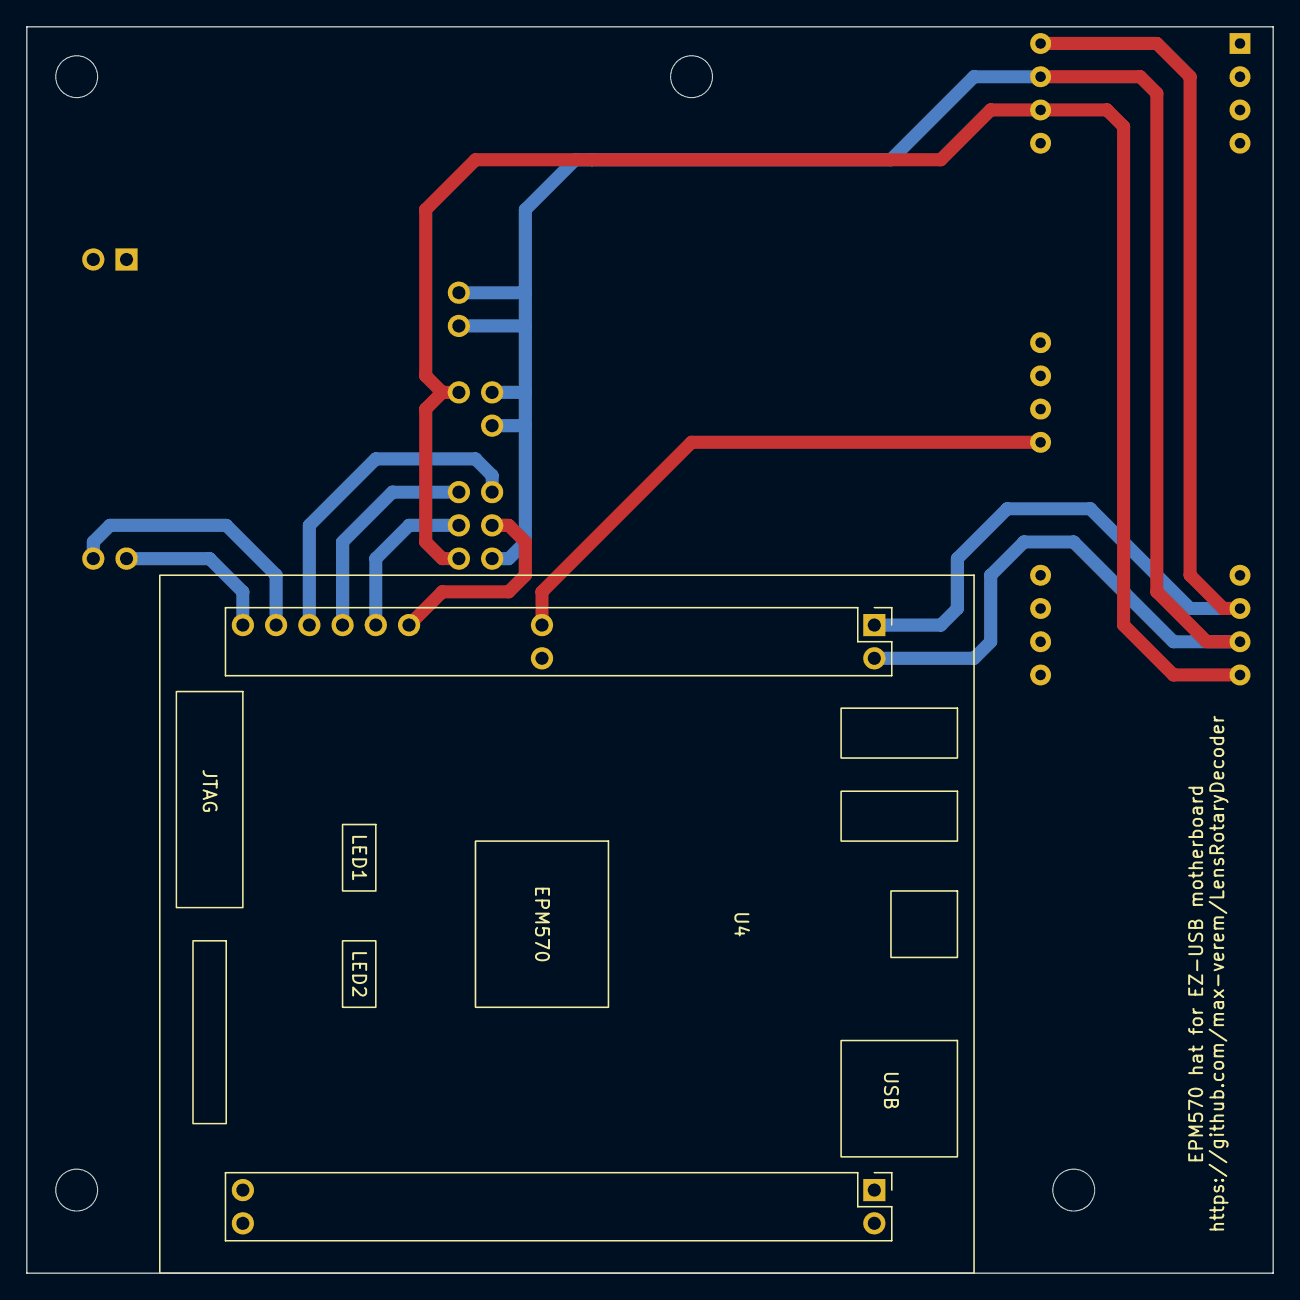
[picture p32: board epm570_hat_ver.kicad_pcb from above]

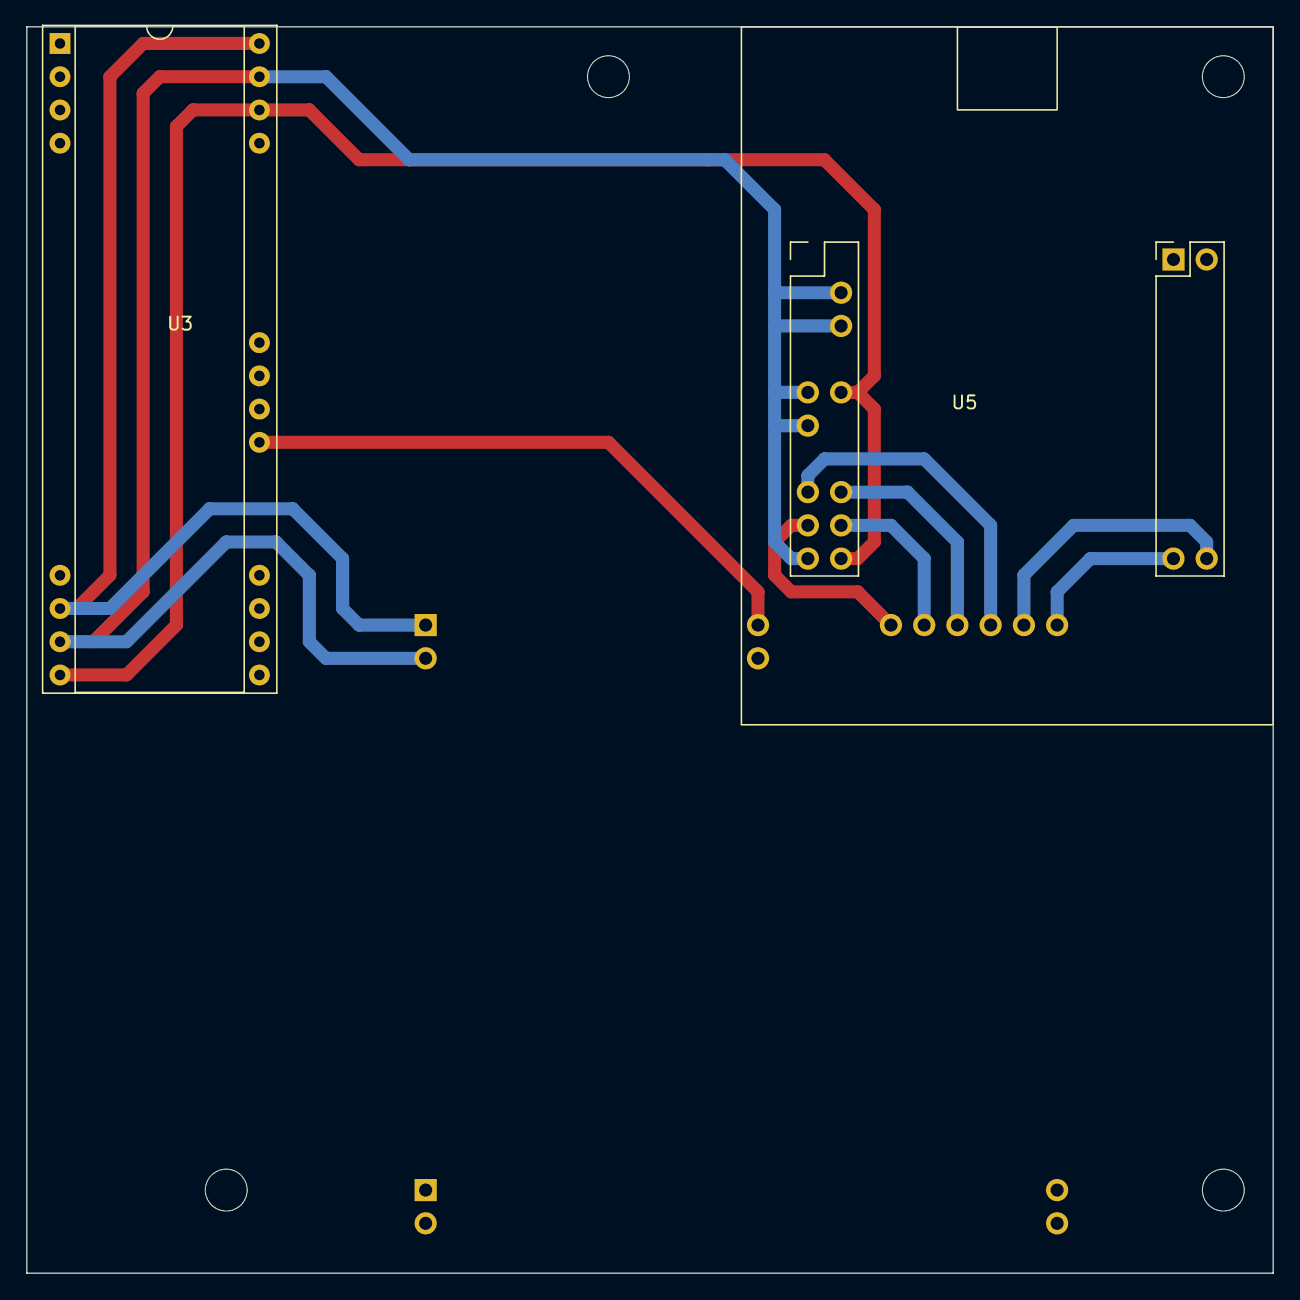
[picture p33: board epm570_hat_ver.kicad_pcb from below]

Board: 2 copper layers, 95.2 x 95.2 mm, 7 parts (2 on the bottom side), 10 nets.

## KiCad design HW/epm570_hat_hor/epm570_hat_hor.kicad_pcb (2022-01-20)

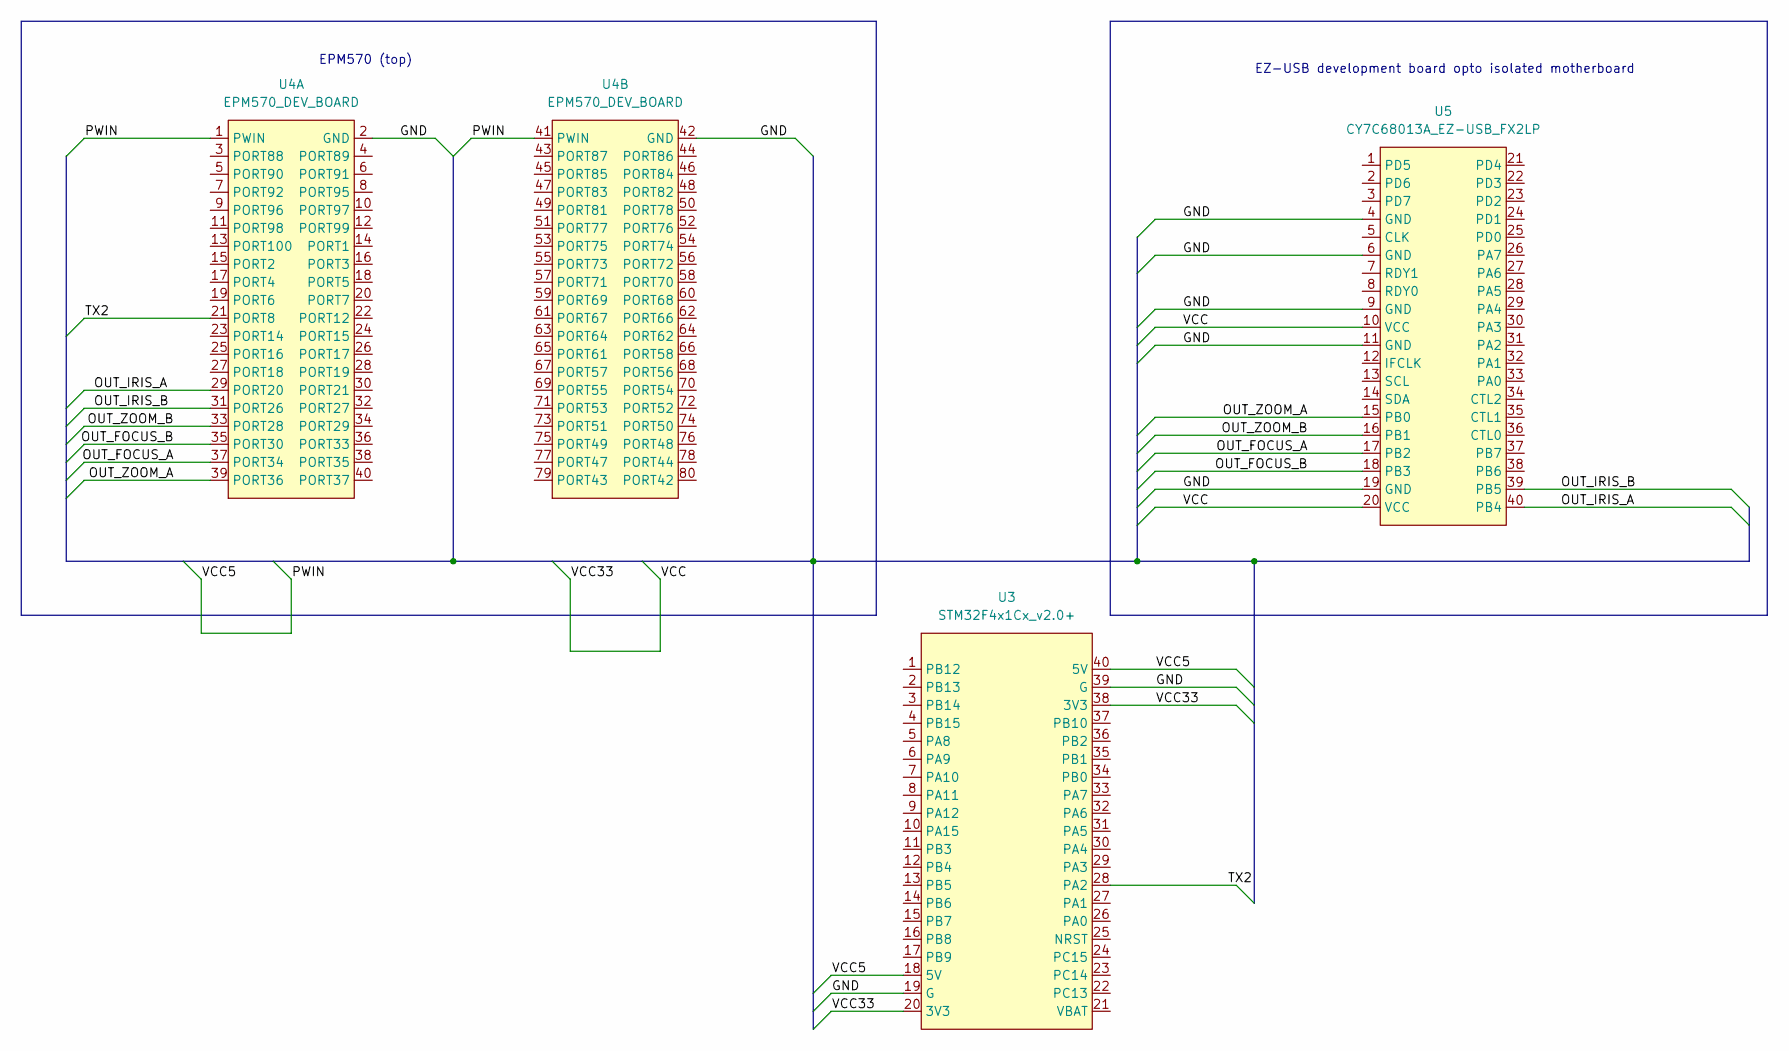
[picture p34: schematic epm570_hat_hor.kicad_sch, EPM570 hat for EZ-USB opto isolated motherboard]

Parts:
U3: STM32F4x1Cx_v2.0+; DIP-40_W15.24mm_LongPads
U4: EPM570_DEV_BOARD
U5: CY7C68013A_EZ-USB_FX2LP

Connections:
/GND: U3.19 (G), U3.39 (G), U4.2 (GND), U4.42 (GND), U5.4 (GND), U5.6 (GND), U5.9 (GND), U5.11 (GND), U5.19 (GND)
/OUT_FOCUS_A: U4.37 (PORT34), U5.17 (PB2)
/OUT_FOCUS_B: U4.35 (PORT30), U5.18 (PB3)
/OUT_IRIS_A: U4.29 (PORT20), U5.40 (PB4)
/OUT_IRIS_B: U4.31 (PORT26), U5.39 (PB5)
/OUT_ZOOM_A: U4.39 (PORT36), U5.15 (PB0)
/OUT_ZOOM_B: U4.33 (PORT28), U5.16 (PB1)
/PWIN: U3.18 (5V), U3.40 (5V), U4.1 (PWIN), U4.41 (PWIN)
/TX2: U3.28 (PA2), U4.21 (PORT8)
/VCC: U3.20 (3V3), U3.38 (3V3), U5.10 (VCC), U5.20 (VCC)

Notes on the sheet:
EZ-USB development board opto isolated motherboard
EPM570 (top)

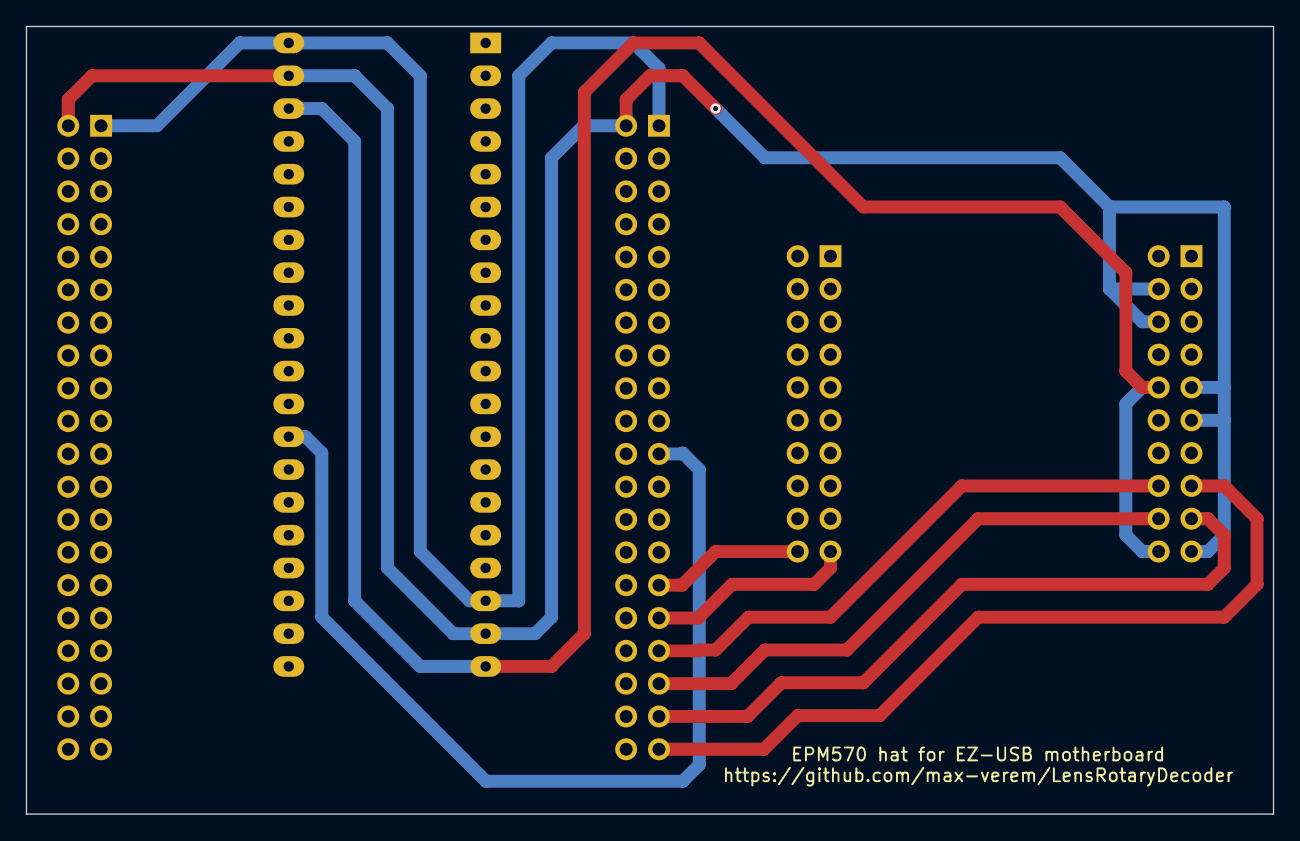
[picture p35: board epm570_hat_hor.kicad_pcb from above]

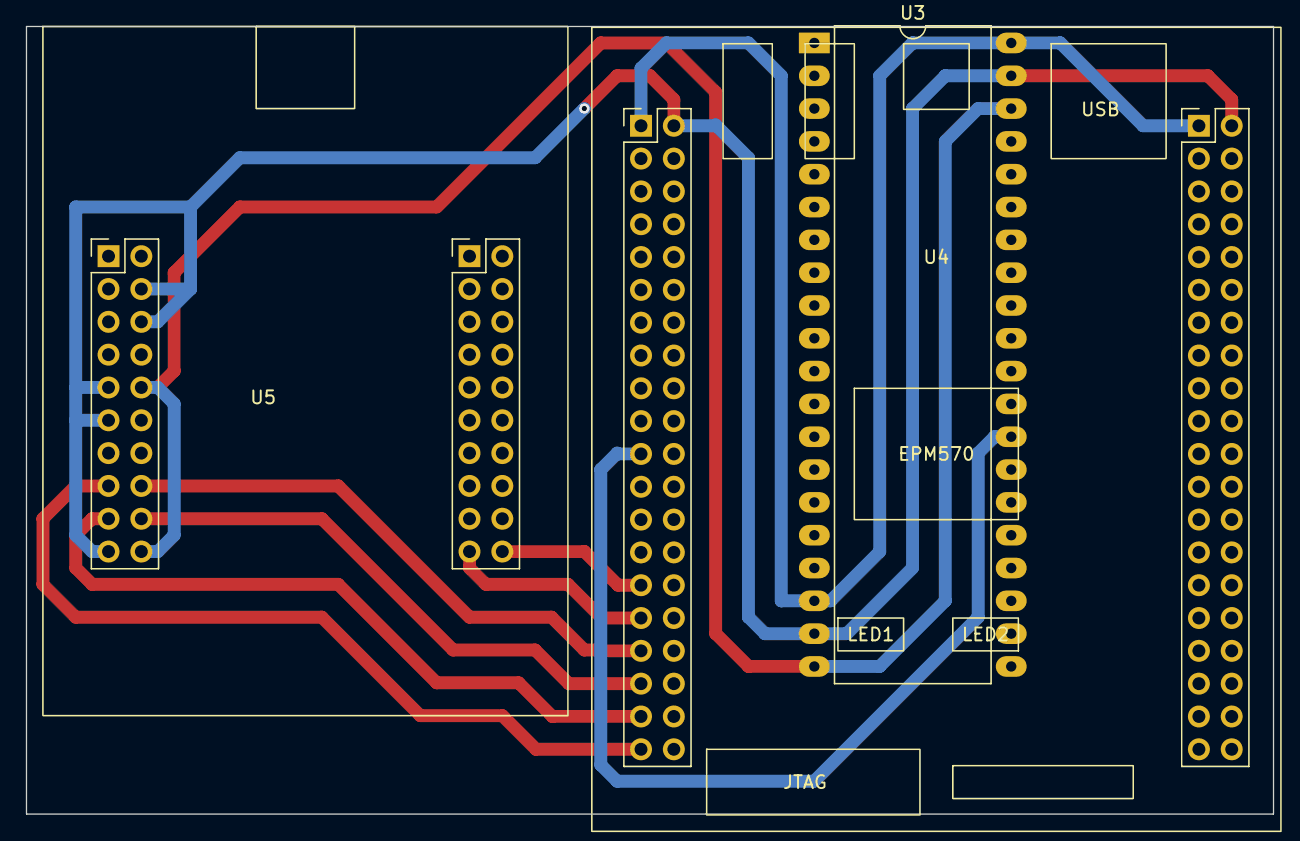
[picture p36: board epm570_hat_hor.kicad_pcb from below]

Board: 2 copper layers, 96.5 x 61.0 mm, 3 parts (3 on the bottom side), 10 nets.

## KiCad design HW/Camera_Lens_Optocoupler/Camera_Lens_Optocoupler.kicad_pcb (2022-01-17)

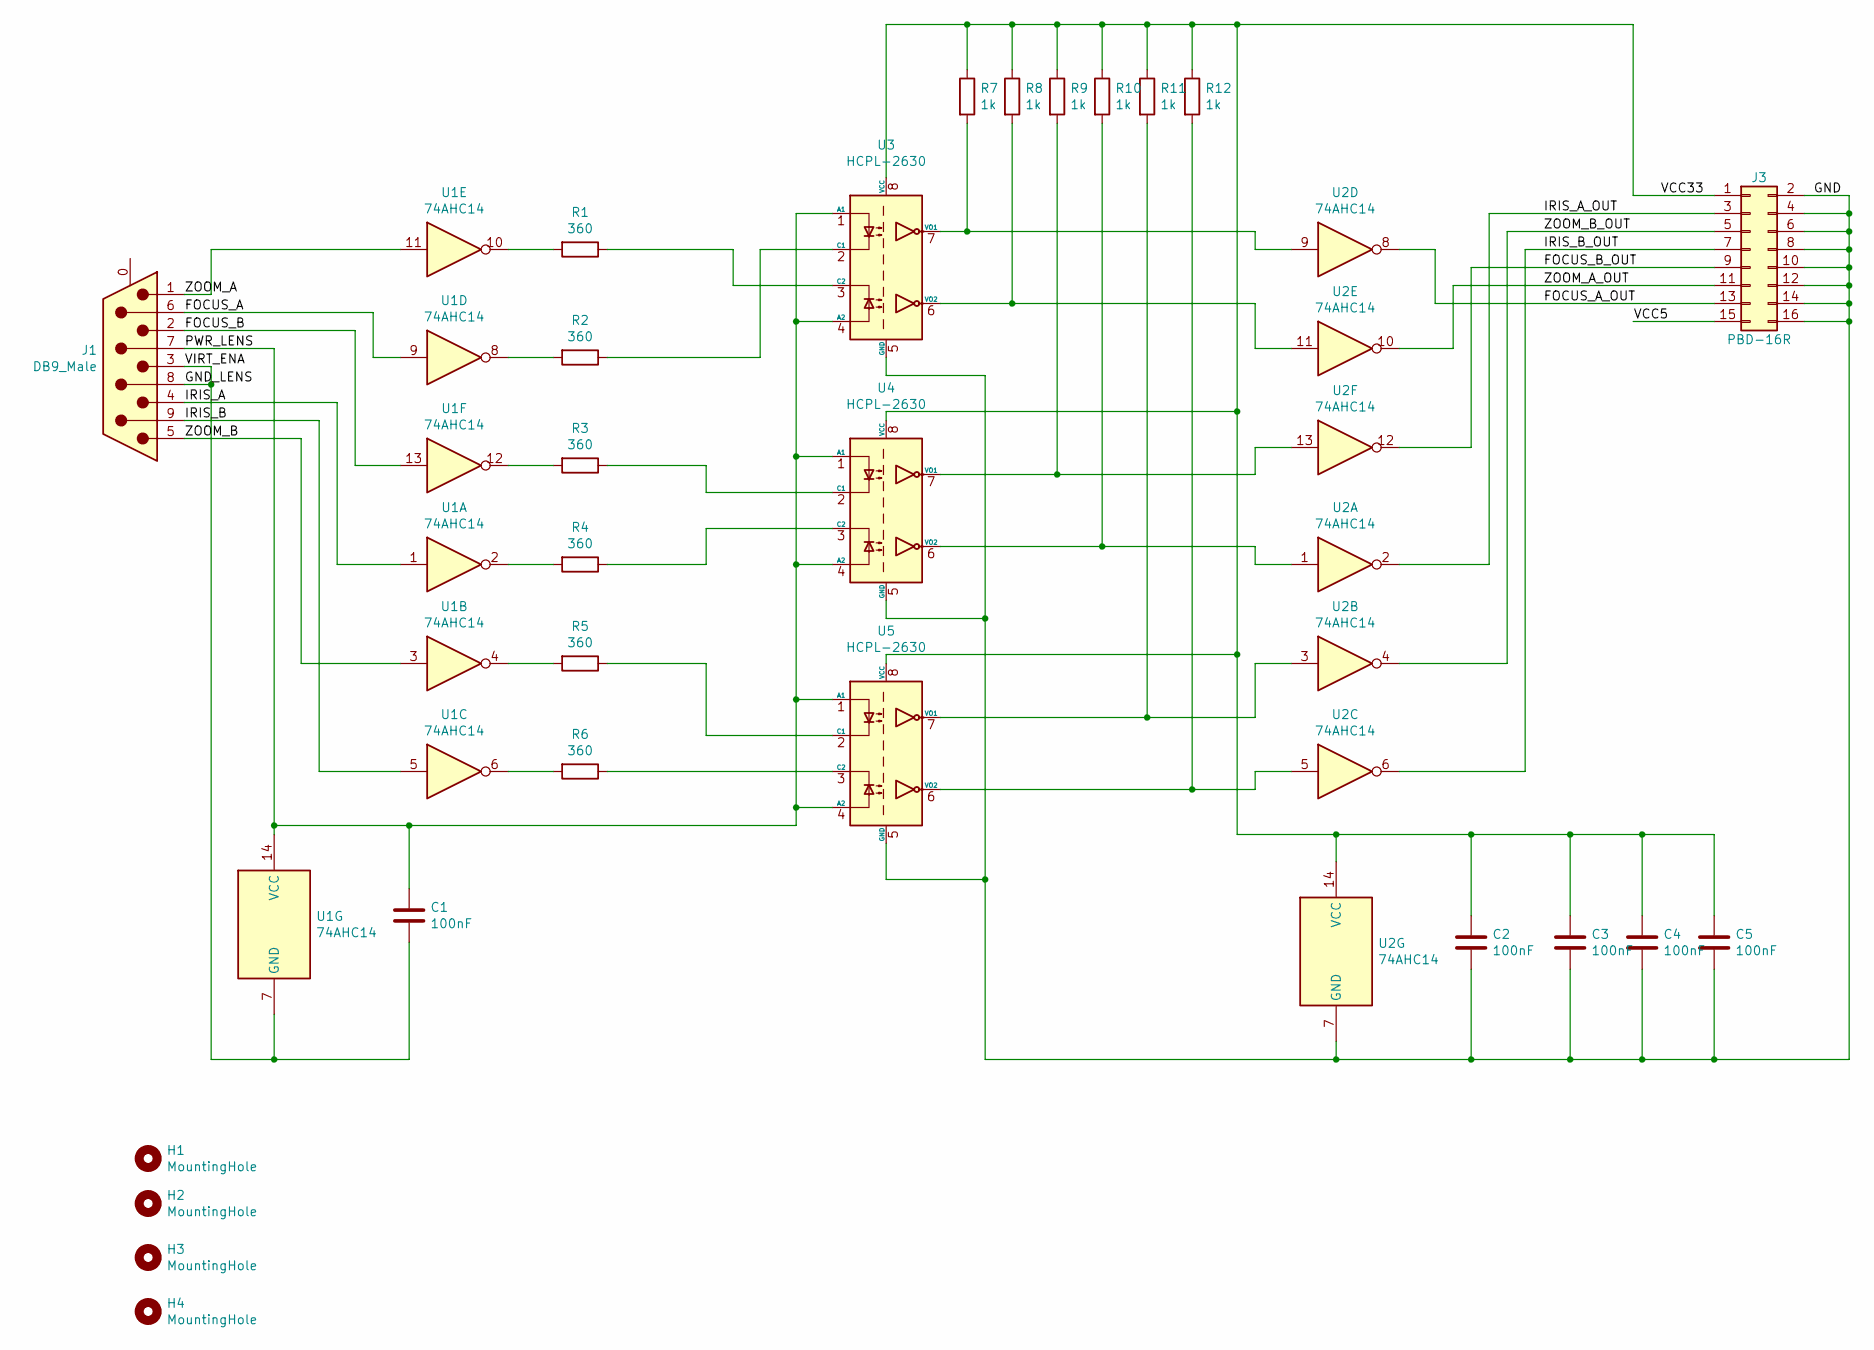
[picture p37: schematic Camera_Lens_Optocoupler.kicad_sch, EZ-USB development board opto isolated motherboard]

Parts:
C1, C2, C3, C4, C5: 100nF; C_Rect_L7.0mm_W2.0mm_P5.00mm
H1, H2, H3, H4: MountingHole; MountingHole_3.2mm_M3
J1: DB9_Male; DSUB-9_Male_Horizontal_P2.77x2.84mm_EdgePinOffset7.70mm_Hou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
J3: PBD-16R; PinSocket_2x08_P2.54mm_Horizontal
R1, R2, R3, R4, R5, R6: 360; R_Axial_DIN0309_L9.0mm_D3.2mm_P12.70mm_Horizontal
R7, R8, R9, R10, R11, R12: 1k; R_Axial_DIN0309_L9.0mm_D3.2mm_P12.70mm_Horizontal
U1, U2: 74AHC14; DIP-14_W7.62mm
U3, U4, U5: HCPL-2630; DIP-8_W7.62mm

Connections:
/FOCUS_A: J1.6, U1.9
/FOCUS_A_OUT: J3.13, U2.8
/FOCUS_B: J1.2, U1.13
/FOCUS_B_OUT: J3.9, U2.12
/GND: C2.2, C3.2, C4.2, C5.2, J3.2, J3.4, J3.6, J3.8, J3.10, J3.12, J3.14, J3.16, U2.7 (GND), U3.5 (GND), U4.5 (GND), U5.5 (GND)
/GND_LENS: C1.2, J1.3, J1.8, U1.7 (GND)
/IRIS_A: J1.4, U1.1
/IRIS_A_OUT: J3.3, U2.2
/IRIS_B: J1.9, U1.5
/IRIS_B_OUT: J3.7, U2.6
/PWR_LENS: C1.1, J1.7, U1.14 (VCC), U3.1 (A1), U3.4 (A2), U4.1 (A1), U4.4 (A2), U5.1 (A1), U5.4 (A2)
/VCC5: J3.15
/VCC33: C2.1, C3.1, C4.1, C5.1, J3.1, R7.1, R8.1, R9.1, R10.1, R11.1, R12.1, U2.14 (VCC), U3.8 (VCC), U4.8 (VCC), U5.8 (VCC)
/ZOOM_A: J1.1, U1.11
/ZOOM_A_OUT: J3.11, U2.10
/ZOOM_B: J1.5, U1.3
/ZOOM_B_OUT: J3.5, U2.4
unnamed: R1.1, U3.3 (C2)
unnamed: R1.2, U1.10
unnamed: R2.2, U1.8
unnamed: R3.2, U1.12
unnamed: R4.2, U1.2
unnamed: R5.2, U1.4
unnamed: R6.2, U1.6
unnamed: R7.2, U2.9, U3.7 (VO1)
unnamed: R8.2, U2.11, U3.6 (VO2)
unnamed: R9.2, U2.13, U4.7 (VO1)
unnamed: R10.2, U2.1, U4.6 (VO2)
unnamed: R11.2, U2.3, U5.7 (VO1)
unnamed: R12.2, U2.5, U5.6 (VO2)
unnamed: R2.1, U3.2 (C1)
unnamed: R3.1, U4.2 (C1)
unnamed: R4.1, U4.3 (C2)
unnamed: R5.1, U5.2 (C1)
unnamed: R6.1, U5.3 (C2)

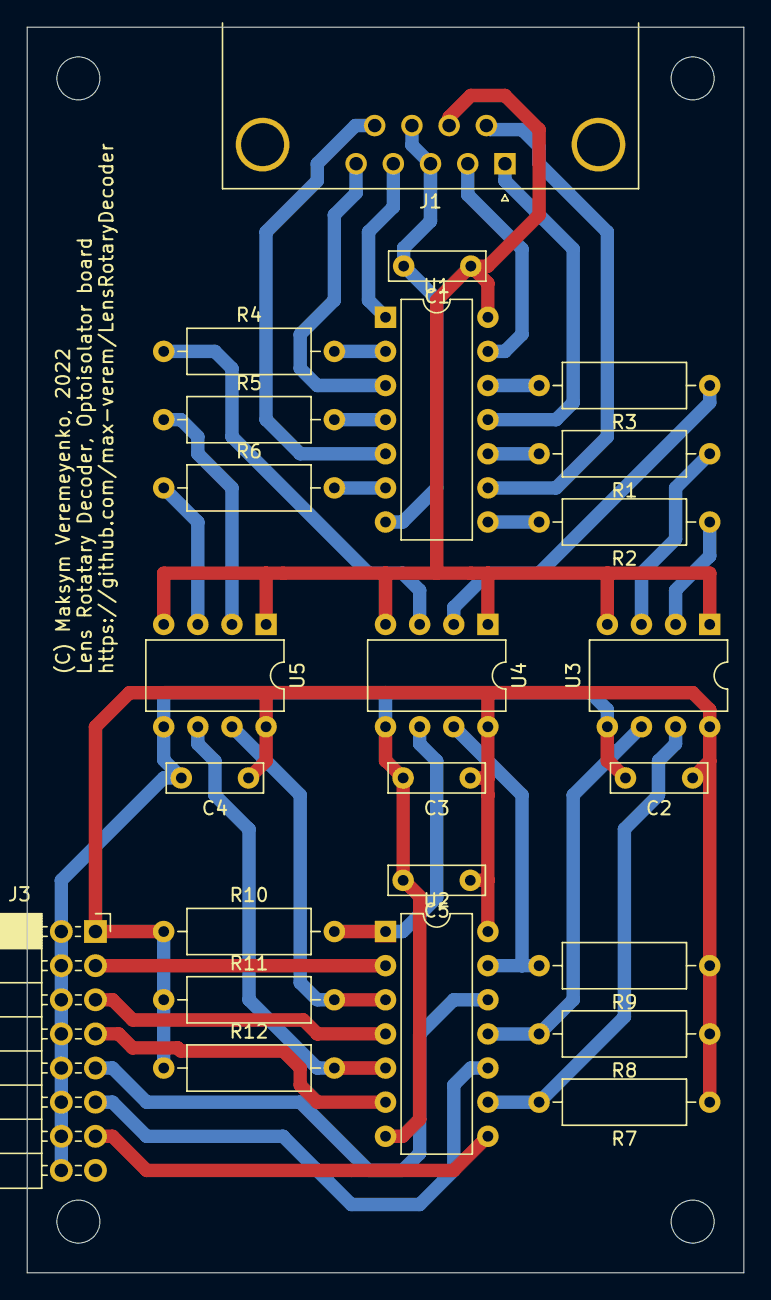
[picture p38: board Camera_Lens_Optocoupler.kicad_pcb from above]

Board: 2 copper layers, 53.3 x 92.7 mm, 28 parts (0 on the bottom side), 34 nets.

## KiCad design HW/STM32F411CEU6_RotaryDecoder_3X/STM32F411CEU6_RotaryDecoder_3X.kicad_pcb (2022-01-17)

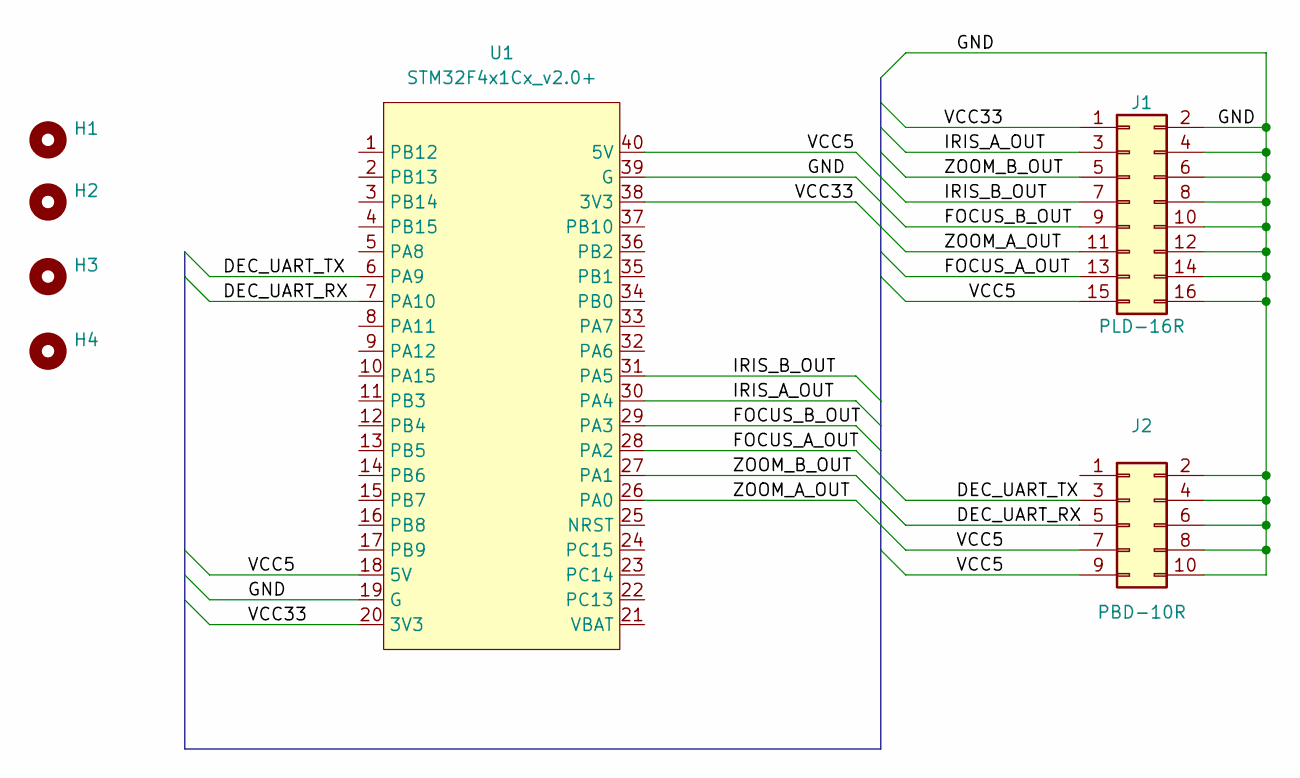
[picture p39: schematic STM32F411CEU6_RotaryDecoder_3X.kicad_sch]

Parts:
H1, H2, H3, H4: MountingHole; MountingHole_3.2mm_M3
J1: PLD-16R; PinHeader_2x08_P2.54mm_Horizontal
J2: PBD-10R; PinSocket_2x05_P2.54mm_Horizontal
U1: STM32F4x1Cx_v2.0+; DIP-40_W15.24mm_LongPads

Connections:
/DEC_UART_RX: J2.5, U1.7 (PA10)
/DEC_UART_TX: J2.3, U1.6 (PA9)
/FOCUS_A_OUT: J1.13, U1.28 (PA2)
/FOCUS_B_OUT: J1.9, U1.29 (PA3)
/GND: J1.2, J1.4, J1.6, J1.8, J1.10, J1.12, J1.14, J1.16, J2.2, J2.4, J2.6, J2.8, J2.10, U1.19 (G), U1.39 (G)
/IRIS_A_OUT: J1.3, U1.30 (PA4)
/IRIS_B_OUT: J1.7, U1.31 (PA5)
/VCC5: J1.15, J2.7, J2.9, U1.18 (5V), U1.40 (5V)
/VCC33: J1.1, U1.20 (3V3), U1.38 (3V3)
/ZOOM_A_OUT: J1.11, U1.26 (PA0)
/ZOOM_B_OUT: J1.5, U1.27 (PA1)

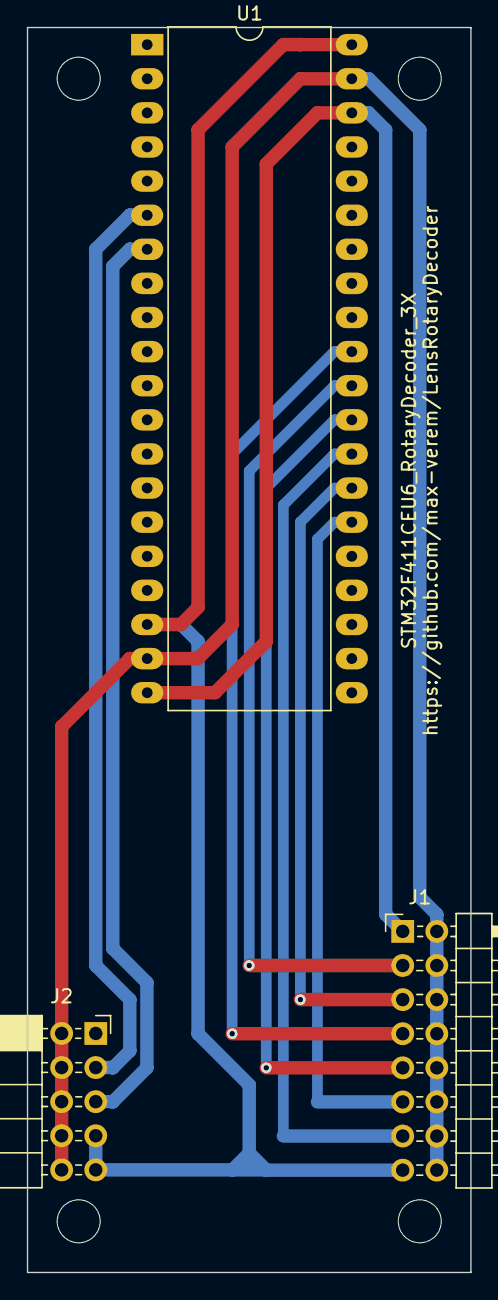
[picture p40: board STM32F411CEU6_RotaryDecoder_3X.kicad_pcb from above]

Board: 2 copper layers, 33.0 x 92.7 mm, 7 parts (0 on the bottom side), 11 nets.

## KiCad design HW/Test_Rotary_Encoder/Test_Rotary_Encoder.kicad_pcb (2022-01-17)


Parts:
C1, C2, C3, C4: 100nF; C_Rect_L7.0mm_W2.0mm_P5.00mm
J1: Conn_02x05_Odd_Even; IDC-Header_2x05_P2.54mm_Vertical
JP1: Jumper_3_Bridged12; PinHeader_1x03_P2.54mm_Vertical
R1, R2, R3, R4, R5, R6: 10K; R_Axial_DIN0309_L9.0mm_D3.2mm_P12.70mm_Horizontal
SW1: RotaryEncoder_Switch; RotaryEncoder_Alps_EC11E-Switch_Vertical_H20mm
U1: 74HC14; DIP-14_W7.62mm

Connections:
/PHASE_A: J1.4, U1.12
/PHASE_B: J1.8, U1.10
/PUSH_BTN: J1.6, U1.8
/VCC: C4.1, JP1.2 (C), R1.1, R2.1, R3.1, U1.14 (VCC)
/VCC5: J1.1, JP1.3 (B)
/VCC33: J1.5, JP1.1 (A)
GND: C1.2, C2.2, C3.2, C4.2, J1.9, SW1.C, SW1.S1, U1.7 (GND)
unnamed: C1.1, R4.2, U1.1
unnamed: C2.1, R5.2, U1.3
unnamed: C3.1, R6.2, U1.5
unnamed: R1.2, R6.1, SW1.S2
unnamed: R2.2, R5.1, SW1.A
unnamed: R3.2, R4.1, SW1.B
unnamed: U1.6, U1.9
unnamed: U1.4, U1.11
unnamed: U1.2, U1.13


Board: 2 copper layers, 87.6 x 27.9 mm, 14 parts (0 on the bottom side), 16 nets.

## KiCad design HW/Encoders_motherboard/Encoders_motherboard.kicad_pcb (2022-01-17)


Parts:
H1, H2, H3, H4: MountingHole; MountingHole_3.2mm_M3
J1, J2, J3: BH-10; IDC-Header_2x05_P2.54mm_Vertical
J4: PBD-16R; PinSocket_2x08_P2.54mm_Horizontal

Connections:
/FOCUS_A_OUT: J2.8, J4.13
/FOCUS_B_OUT: J2.4, J4.9
/GND: J1.9, J2.9, J3.9, J4.2, J4.4, J4.6, J4.8, J4.10, J4.12, J4.14, J4.16
/IRIS_A_OUT: J3.8, J4.3
/IRIS_B_OUT: J3.4, J4.7
/VCC5: J1.1, J2.1, J3.1, J4.15
/VCC33: J1.5, J2.5, J3.5, J4.1
/ZOOM_A_OUT: J1.8, J4.11
/ZOOM_B_OUT: J1.4, J4.5


Board: 2 copper layers, 29.2 x 92.7 mm, 8 parts (0 on the bottom side), 9 nets.

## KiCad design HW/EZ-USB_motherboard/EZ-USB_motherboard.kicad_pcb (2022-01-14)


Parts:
C1, C2, C3, C4, C5: 100nF; C_Rect_L7.0mm_W2.0mm_P5.00mm
H1, H2, H3, H4, H5, H6, H7, H8, H9, H10: MountingHole; MountingHole_3.2mm_M3
J1: DB9_Male_MountingHoles; DSUB-9_Male_Horizontal_P2.77x2.84mm_EdgePinOffset9.90mm_Hou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
JP1, JP2: Jumper_2_Open; PinHeader_1x02_P2.54mm_Vertical
R1, R2, R3, R4, R5, R6: 360; R_Axial_DIN0309_L9.0mm_D3.2mm_P12.70mm_Horizontal
R7, R8, R9, R10, R11, R12: 1k; R_Axial_DIN0309_L9.0mm_D3.2mm_P12.70mm_Horizontal
U1, U2: 74AHC04; DIP-14_W7.62mm
U3, U4, U5: HCPL-2630; DIP-8_W7.62mm
U6: CY7C68013A_EZ-USB_FX2LP

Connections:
/FOCUS_A: J1.6, U1.11
/FOCUS_B: J1.2, U1.13
/GND: C1.2, J1.3, J1.8, JP2.1 (A), U1.7 (GND)
/IRIS_A: J1.4, U1.1
/IRIS_B: J1.9, U1.3
/OUT_FOCUS_A: U2.10, U6.17 (PB2)
/OUT_FOCUS_B: U2.8, U6.18 (PB3)
/OUT_IRIS_A: U2.6, U6.40 (PB4)
/OUT_IRIS_B: U2.4, U6.39 (PB5)
/OUT_ZOOM_A: U2.12, U6.15 (PB0)
/OUT_ZOOM_B: U2.2, U6.16 (PB1)
/PWR: C1.1, J1.7, JP1.1 (A), U1.14 (VCC), U3.1 (A1), U3.4 (A2), U4.1 (A1), U4.4 (A2), U5.1 (A1), U5.4 (A2)
/ZOOM_A: J1.1, U1.9
/ZOOM_B: J1.5, U1.5
unnamed: C2.1, C3.1, C4.1, C5.1, JP1.2 (B), R7.1, R8.1, R9.1, R10.1, R11.1, R12.1, U2.14 (VCC), U3.8 (VCC), U4.8 (VCC), U5.8 (VCC), U6.10 (VCC), U6.20 (VCC)
unnamed: C2.2, C3.2, C4.2, C5.2, JP2.2 (B), U2.7 (GND), U3.5 (GND), U4.5 (GND), U5.5 (GND), U6.4 (GND), U6.6 (GND), U6.9 (GND), U6.11 (GND), U6.19 (GND)
unnamed: R1.1, U4.2 (C1)
unnamed: R1.2, U1.8
unnamed: R2.1, U3.3 (C2)
unnamed: R2.2, U1.10
unnamed: R3.1, U3.2 (C1)
unnamed: R3.2, U1.12
unnamed: R4.1, U5.3 (C2)
unnamed: R4.2, U1.2
unnamed: R5.1, U5.2 (C1)
unnamed: R5.2, U1.4
unnamed: R6.1, U4.3 (C2)
unnamed: R6.2, U1.6
unnamed: R7.2, U2.9, U3.7 (VO1)
unnamed: R8.2, U2.11, U3.6 (VO2)
unnamed: R9.2, U2.13, U4.7 (VO1)
unnamed: R10.2, U2.1, U4.6 (VO2)
unnamed: R11.2, U2.3, U5.7 (VO1)
unnamed: R12.2, U2.5, U5.6 (VO2)


Board: 2 copper layers, 109.2 x 95.2 mm, 36 parts (1 on the bottom side), 34 nets.

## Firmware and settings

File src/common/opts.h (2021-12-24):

#define DEFAULT_INSTANCE_SET_OPTS                                               \
            case '6':   /* --log-file-name              */                      \
                ST_STR(log_file_name, PATH_MAX);                                \
            case '7':   /* --log-rotate-interval        */                      \
                ST_INT(log_rotate_interval);                                    \
                                                                                \
            case 'd':   /* --demonize                   */                      \
                ST_FLAG(f_demonize);                                            \
                                                                                \
            case 'n':   /* --nodemonize                 */                      \
                ST_FLAG(f_nodemonize);                                          \
                                                                                \
            case 250:   /* --realtime-io                */                      \
                ST_FLAG(f_realtime_io);                                         \
                                                                                \
            case 249:   /* --cpu-affinity               */                      \
                ST_INT(cpu_affinity);                                           \
                                                                                \
            case 248:   /* --debug                      */                      \
                instance->f_debug++; break;                                     \
                                                                                \
            case 247:   /* --realtime-cpu               */                      \
                ST_INT(realtime_cpu);                                           \
                                                                                \
            case 'h':                                                           \
                instance_usage(NULL);                                           \
                return -1;                                                      \
                break;                                                          \
                                                                                \
            default:                                                            \
                fprintf(stderr,                                                 \
                    "ERROR: Incorrect argument! [%s]\n", argv[optind - 1]);     \
                instance_usage(NULL);                                           \
                return -1;                                                      \
                break;

#define DEFAULT_INSTANCE_USAGE                                                  \
        "    --demonize                         Become daemon on executing\n"   \
        "\n"                                                                    \
        "                                       Log file operation\n"           \
        "    --log-file-name=<STR>\n"                                           \
        "    --log-rotate-interval=<INT>\n"                                     \
        "\n"                                                                    \
        "    -h, --help                         Show this help and usage\n"

#define DEFAULT_INSTANCE_LONG_OPTS                                              \
    { "log-file-name",                  required_argument, NULL, '6'},          \
    { "log-rotate-interval",            required_argument, NULL, '7'},          \
    { "demonize",                       no_argument,       NULL, 'd'},          \
    { "nodemonize",                     no_argument,       NULL, 'n'},          \
    { "help",                           no_argument,       NULL, 'h'},          \
    { "realtime-io",                    no_argument,       NULL, 250},          \
    { "cpu-affinity",                   required_argument, NULL, 249},          \
    { "debug",                          no_argument,       NULL, 248},          \
    { "realtime-cpu",                   required_argument, NULL, 247},          \
    { 0, 0, 0, 0}

/* program arguments processing */
#define ST_STR(VAR, MAX_LEN) strncpy(instance->VAR, optarg, MAX_LEN); break;
#define ST_INT(VAR) instance->VAR = atoi(optarg); break;
#define ST_FLAG(VAR) instance->VAR = 1; break;

#define REQ_STR(ARG, VAL) if(0 == instance->VAL[0]) req_arg = ARG; else
#define REQ_INT(ARG, VAL) if(0 == instance->VAL) req_arg = ARG; else

#define OPTS_FROM_FILE_CB(PROC) \
static int opts_from_file_cb(int argc, char** argv, void* app) \
{ \
    return PROC((instance_t*)app, argc, argv); \
}

#define OPTS_FROM_FILE_PROCESS(APP) \
    for(c = 0; optind < argc; optind++) \
    { \
        const char* f = argv[optind]; \
        if(!opts_from_file(f, APP, opts_from_file_cb)) \
            strlcpy(instance->last_opts_file, f, PATH_MAX); \
        else \
            c++; \
    };


static int opts_from_file(const char* filename, void* instance, int (*cb)(int, char**, void*))
{
    FILE *f;
    int args_count = 0, r = 0, l;
    char *buf;
    char** args_list;

    f = fopen(filename, "rt");
    if(!f)
    {
        fprintf(stderr, "%s: failed to open [%s]\n", __FUNCTION__, filename);
        return 1;
    };

    buf = (char*)malloc(PATH_MAX);
    args_list = (char**)malloc(sizeof(char*) * PATH_MAX);
    memset(args_list, 0, sizeof(char*) * PATH_MAX);

    args_list[0] = strdup(filename);
    args_count = 1;

    while(!feof(f))
    {
        char *c;

        buf[0] = 0;
        fgets(buf, PATH_MAX, f);

        /* trim from end */
        for(l = strlen(buf); l > 0;)
        {
            if(strchr("\n\t\r ", buf[l - 1]))
            {
                buf[l - 1] = 0;
                l--;
            }
            else
                break;
        };

        /* trim from start */
        for(c = buf; c[0];)
        {
            if(strchr("\n\t\r ", c[0]))
                c++;
            else
                break;
        };

        /* non-empty */
        if(!c[0] || c[0] == '#')
            continue;

        args_list[args_count++] = strdup(c);
    };

    free(buf);

    if(args_count > 1)
        r = cb(args_count, args_list, instance);

    for(l = 0; l < args_count; l++)
        free(args_list[l]);
    free(args_list);

    fclose(f);

    return r;
};

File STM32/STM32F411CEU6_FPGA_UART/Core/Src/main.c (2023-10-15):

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
/* Includes ------------------------------------------------------------------*/
#include "main.h"
#include "usb_device.h"

/* USER CODE BEGIN Includes */
#include "app.h"
#include "usbd_customhid.h"
/* USER CODE END Includes */

I2C_HandleTypeDef hi2c1;
I2C_HandleTypeDef hi2c2;
DMA_HandleTypeDef hdma_i2c1_tx;
DMA_HandleTypeDef hdma_i2c2_tx;

SPI_HandleTypeDef hspi1;
SPI_HandleTypeDef hspi2;
DMA_HandleTypeDef hdma_spi1_rx;
DMA_HandleTypeDef hdma_spi1_tx;
DMA_HandleTypeDef hdma_spi2_rx;
DMA_HandleTypeDef hdma_spi2_tx;

TIM_HandleTypeDef htim1;

UART_HandleTypeDef huart1;
DMA_HandleTypeDef hdma_usart1_rx;

void SystemClock_Config(void);
static void MX_GPIO_Init(void);
static void MX_DMA_Init(void);
static void MX_USART1_UART_Init(void);
static void MX_I2C1_Init(void);
static void MX_SPI1_Init(void);
static void MX_I2C2_Init(void);
static void MX_TIM1_Init(void);
static void MX_SPI2_Init(void);
/* USER CODE BEGIN 0 */

// ---------------------------------------------------

#ifdef DEBUG123

#include <stdio.h>
#include <errno.h>
//#include  <sys/unistd.h> // STDOUT_FILENO, STDERR_FILENO

int _write(int file, char *data, int len)
{
   // arbitrary timeout 1000
   HAL_StatusTypeDef status =
      HAL_UART_Transmit(&huart1, (uint8_t*)data, len, 1000);

   // return # of bytes written - as best we can tell
   return (status == HAL_OK ? len : 0);
}

#endif

// ---------------------------------------------------

/* USER CODE END 0 */

/**
  * @brief  The application entry point.
  * @retval int
  */
int main(void)
{
  /* MCU Configuration--------------------------------------------------------*/

  /* Reset of all peripherals, Initializes the Flash interface and the Systick. */
  HAL_Init();

  /* USER CODE BEGIN Init */
  app_init();
  /* USER CODE END Init */

  /* Configure the system clock */
  SystemClock_Config();

  /* Initialize all configured peripherals */
  MX_GPIO_Init();
  MX_DMA_Init();
  MX_USB_DEVICE_Init();
  MX_USART1_UART_Init();
  MX_I2C1_Init();
  MX_SPI1_Init();
  MX_I2C2_Init();
  MX_TIM1_Init();
  MX_SPI2_Init();
  /* USER CODE BEGIN 2 */
  app_begin();
  /* USER CODE END 2 */

  /* Infinite loop */
  /* USER CODE BEGIN WHILE */
  while (1)
  {
	app_loop();
    /* USER CODE END WHILE */

    /* USER CODE BEGIN 3 */
  }
  /* USER CODE END 3 */
}

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


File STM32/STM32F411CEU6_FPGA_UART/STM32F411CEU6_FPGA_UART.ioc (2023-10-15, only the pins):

Mcu.UserName=STM32F411CEUx
PA10.Signal=USART1_RX
PA11.Signal=USB_OTG_FS_DM
PA12.Signal=USB_OTG_FS_DP
PA13.Signal=SYS_JTMS-SWDIO
PA14.Signal=SYS_JTCK-SWCLK
PA5.Signal=SPI1_SCK
PA6.Signal=SPI1_MISO
PA7.Signal=SPI1_MOSI
PA9.Signal=USART1_TX
PB0.GPIO_Label=W5500_SCS
PB0.Signal=GPIO_Output
PB1.GPIO_Label=W5500_RST
PB1.Signal=GPIO_Output
PB10.Signal=I2C2_SCL
PB13.Signal=SPI2_SCK
PB14.Signal=SPI2_MISO
PB15.Signal=SPI2_MOSI
PB3.Signal=I2C2_SDA
PB6.Signal=I2C1_SCL
PB7.Signal=I2C1_SDA
PB8.Signal=GPXTI8
PB9.Signal=GPXTI9
PC13-ANTI_TAMP.GPIO_Label=LED_PIN
PC13-ANTI_TAMP.Signal=GPIO_Output
PC14-OSC32_IN.Signal=RCC_OSC32_IN
PC15-OSC32_OUT.Signal=RCC_OSC32_OUT

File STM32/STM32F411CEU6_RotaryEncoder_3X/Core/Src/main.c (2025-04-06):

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
/* Includes ------------------------------------------------------------------*/
#include "main.h"
#include "dma.h"
#include "tim.h"
#include "gpio.h"


void SystemClock_Config(void);
/* USER CODE BEGIN 0 */
#define Lo(PIN) (PIN << 16)
#define Hi(PIN) (PIN <<  0)

static uint32_t seq1[4] = {
	Lo(ROT_A1_Pin) | Lo(ROT_B1_Pin),
	Hi(ROT_A1_Pin) | Lo(ROT_B1_Pin),
	Hi(ROT_A1_Pin) | Hi(ROT_B1_Pin),
	Lo(ROT_A1_Pin) | Hi(ROT_B1_Pin)
};

static uint32_t seq2[4] = {
	Lo(ROT_A2_Pin) | Lo(ROT_B2_Pin),
	Hi(ROT_A2_Pin) | Lo(ROT_B2_Pin),
	Hi(ROT_A2_Pin) | Hi(ROT_B2_Pin),
	Lo(ROT_A2_Pin) | Hi(ROT_B2_Pin)
};

static uint32_t seq3[4] = {
	Lo(ROT_A3_Pin) | Lo(ROT_B3_Pin),
	Hi(ROT_A3_Pin) | Lo(ROT_B3_Pin),
	Hi(ROT_A3_Pin) | Hi(ROT_B3_Pin),
	Lo(ROT_A3_Pin) | Hi(ROT_B3_Pin)
};

static void rotary_seq_out(TIM_HandleTypeDef* tim, GPIO_TypeDef *gpio, uint32_t *buf, int size)
{
	HAL_DMA_Start_IT(
		tim->hdma[TIM_DMA_ID_UPDATE],
		(uint32_t)buf,
		(uint32_t)&(gpio->BSRR), size);
	__HAL_TIM_ENABLE_DMA(tim, TIM_DMA_UPDATE ); 	//Enable the TIM Update DMA request
	__HAL_TIM_ENABLE(tim);                 		//Enable the Peripheral
}

#define CNT_MAX 3
#define CNT_PREV 0
#define CNT_CURR 1
volatile int cnt[CNT_MAX][2];
static uint32_t *seqs[CNT_MAX] = {seq1, seq2, seq3};

#define MAX_ROT_COUNT 128
static uint32_t rotary_seq_buf[2][MAX_ROT_COUNT];
volatile int rotary_seq_idx = 0, rotary_seq_size = 0;

static void timer_2ms(TIM_HandleTypeDef *htim)
{
	int i, j;
	uint32_t *rotary_seq_data = rotary_seq_buf[rotary_seq_idx];

	HAL_GPIO_WritePin(TP1_GPIO_Port, TP1_Pin, rotary_seq_idx ? GPIO_PIN_SET : GPIO_PIN_RESET);
	HAL_GPIO_WritePin(TP2_GPIO_Port, TP2_Pin, GPIO_PIN_SET);

	/* send rotary sequence if present */
	if(rotary_seq_size)
	{
		/* send */
		rotary_seq_out(&htim1, ROT_A3_GPIO_Port, rotary_seq_data, rotary_seq_size);

		/* rotate buffer */
		rotary_seq_size = 0;
		rotary_seq_idx ^= 1;
		rotary_seq_data = rotary_seq_buf[rotary_seq_idx];
	}

	for(i = 0; i < MAX_ROT_COUNT; i++)
	{
		uint32_t v = 0, m = 0;

		for(j = 0; j < CNT_MAX; j++)
		{
			int step;

			/* skip cycle if no counter value changed */
			if(cnt[j][CNT_CURR] == cnt[j][CNT_PREV])
				continue;

			/* mark this counter has updated */
			m |= 1 << j;

			/* calc next value */
			if(cnt[j][CNT_PREV] < cnt[j][CNT_CURR])
				cnt[j][CNT_PREV]++;
			else
				cnt[j][CNT_PREV]--;

			/* calc step */
			step = cnt[j][CNT_PREV] % 4;
			if(step < 0) step += 4;

			/* store value */
			v |= seqs[j][step];
		};

		/* check if any number written */
		if(!m)
			break;

		/* store to rot array */
		rotary_seq_data[i] = v;
	}
	rotary_seq_size = i;

	HAL_GPIO_WritePin(TP2_GPIO_Port, TP2_Pin, GPIO_PIN_RESET);
};


/* USER CODE END 0 */

/**
  * @brief  The application entry point.
  * @retval int
  */
int main(void)
{

  /* USER CODE BEGIN 1 */
	uint8_t j = 0;

  /* USER CODE END 1 */

  /* MCU Configuration--------------------------------------------------------*/

  /* Reset of all peripherals, Initializes the Flash interface and the Systick. */
  HAL_Init();

  /* Configure the system clock */
  SystemClock_Config();

  /* Initialize all configured peripherals */
  MX_GPIO_Init();
  MX_DMA_Init();
  MX_TIM1_Init();
  MX_TIM3_Init();
  /* USER CODE BEGIN 2 */
  HAL_GPIO_WritePin(LED_GPIO_Port, LED_Pin, GPIO_PIN_RESET);

  // start generic timer
  HAL_TIM_RegisterCallback(&htim3, HAL_TIM_PERIOD_ELAPSED_CB_ID, timer_2ms);
  HAL_TIM_Base_Start_IT(&htim3);

  /* USER CODE END 2 */

  /* Infinite loop */
  /* USER CODE BEGIN WHILE */
  while (1)
  {
	/* wait for key press */
	while(HAL_GPIO_ReadPin(KEY_GPIO_Port, KEY_Pin) == GPIO_PIN_SET);

	/* fake next counters */
	__disable_irq();
	cnt[0][CNT_CURR] += 200; // + rotary_seq_idx;
	__enable_irq();
	HAL_Delay(1);
	__disable_irq();
	cnt[1][CNT_CURR] -= 200; // + rotary_seq_idx;
	__enable_irq();
	HAL_Delay(1);
	__disable_irq();
	cnt[2][CNT_CURR] += j ? 100 : -100;
	__enable_irq();

	j ^= 1;

    HAL_GPIO_WritePin(LED_GPIO_Port, LED_Pin, GPIO_PIN_SET);

	/* sleep for contact bounces */
	HAL_Delay(200);

	/* wait for key release */
	while(HAL_GPIO_ReadPin(KEY_GPIO_Port, KEY_Pin) == GPIO_PIN_RESET);

	/* sleep for contact bounces */
	HAL_Delay(200);

    HAL_GPIO_WritePin(LED_GPIO_Port, LED_Pin, GPIO_PIN_RESET);

    /* USER CODE END WHILE */

    /* USER CODE BEGIN 3 */
  }
  /* USER CODE END 3 */
}

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


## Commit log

2021-10-13 Fix setting initial value byte order
    [main.c]
2021-10-13 Clone project for STM32F411CEU6 mcu
2021-10-13 Revert byte order change
    [main.c]
2021-12-24 decoder1 scheme/pcb added
    [decoder1.kicad_pcb, decoder1.sch]
2021-12-24 Re-organize directories for pcb/schematic
    [decoder1.kicad_pcb, decoder1.sch]
2021-12-30 Enable pullup resistors on STM's pins
2021-12-30 add stm32 rotary decoder skeleton
2021-12-30 Implement getting rotary decoder data from STM32 usb dongle
2021-12-30 Update USB VID/PID
2022-01-04 Rename STM32 projects
2022-01-04 Cleanup STM32 projects tree
2022-01-04 Cleanup STM32 projects tree, prepare new project tree
2022-01-04 Add UART code to STM32 project
2022-01-05 uart HAL_Drivers added
2022-01-05 Bypass all UART bytestream to HID
2022-01-05 Convert Schematic/PCB to KiCad6.0 format
    [Camera_Lens_Optocoupler.kicad_pcb, Camera_Lens_Optocoupler.kicad_sch, EZ-USB_motherboard.kicad_pcb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]
2022-01-05 Add Kicad-STM32 module for schematic projects
2022-01-05 Camera Lens Cable schematic added
    [Camera_Lens_Cable.kicad_pcb, Camera_Lens_Cable.kicad_sch]
2022-01-05 Update STM32 clock generation config
2022-01-06 Enable timers and dma for futher tests
2022-01-06 Rename STM32 project: F411 would be 3X rotation decoder
2022-01-06 Clone and rename stm32_rot_dec into two different reader for compatibility
2022-01-06 Fix STM32 decoders projects split
2022-01-06 Cleanup STM32F411CEU6_RotaryDecoder_3X project
2022-01-06 DMA GPIO reading skeleton
2022-01-07 Test rotary encoder schematic/pcb added
    [Camera_Lens_Cable.kicad_pcb, Camera_Lens_Cable.kicad_sch, Camera_Lens_Optocoupler.kicad_pcb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]
2022-01-11 Implement table based STM32 rotary decoder
2022-01-11 Cleanup STM32 decoder code, specify constants for table and calc based algorithms
2022-01-12 Initial UART code support added
2022-01-12 Add new modules for STM-UART project
2022-01-14 I2C to 40000, DMA FIFO, Burst mode
2022-01-14 Sync EZ-USB based decoder to latest version
    [EZ-USB_motherboard.kicad_pcb, EZ-USB_motherboard.kicad_sch]
2022-01-17 UART output startup added
2022-01-17 Rework packet header, enable fifo and burst mode
    [STM32F411CEU6_RotaryDecoder_3X.ioc, main.c]
2022-01-17 Sync schematic and pcb with git head
    [Camera_Lens_Optocoupler.kicad_pcb, Camera_Lens_Optocoupler.kicad_sch, Encoders_motherboard.kicad_pcb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]
2022-01-18 Restore timer setting throw contstants
2022-01-19 UART to NET skeleton
2022-01-19 Minimal UDP sender skeleton for STM32
2022-01-19 Enable IRQ for UART, setup 230400 baudrate
2022-01-20 Save some obsolete projects
    [epm570_hat_hor.kicad_pcb, epm570_hat_hor.kicad_sch, epm570_hat_ver.kicad_pcb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]
2022-01-21 Add schematic and pcb of decoder with OLED and NET support
    [MCU_NET_OLED.kicad_pcb, MCU_NET_OLED.kicad_sch]
2022-01-21 Add macros to select SPI used for W5500
2022-01-25 Fix syncing thread of ez-usb reader
2022-01-25 Add options description for stm32_rot_dec_3x1 reader
2022-01-27 Start documenting camera cable
2022-01-27 Start documenting ez-usb board
2022-02-11 Added photo of EZ-USB based device
2022-02-14 Set SO_BROADCAST option to socket
2023-10-15 Rework STM32F411CEU6_FPGA_UART project
2023-10-15 Rework STM32F411CEU6_RotaryDecoder_3X project
2025-04-06 Drop old STM32F411CEU6_RotaryDecoder_3X
2025-04-06 Added rotary encoder emulator STM32F411CEU6_RotaryEncoder_3X
2025-04-06 Added updated STM32F411CEU6_RotaryDecoder_3X
2025-04-06 Switch to binary uart packet, build release version

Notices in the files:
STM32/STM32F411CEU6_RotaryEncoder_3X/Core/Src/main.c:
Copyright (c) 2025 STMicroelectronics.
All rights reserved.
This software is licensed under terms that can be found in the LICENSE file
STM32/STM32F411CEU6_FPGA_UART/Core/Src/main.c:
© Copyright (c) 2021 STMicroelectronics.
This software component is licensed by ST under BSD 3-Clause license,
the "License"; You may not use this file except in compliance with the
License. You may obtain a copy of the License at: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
